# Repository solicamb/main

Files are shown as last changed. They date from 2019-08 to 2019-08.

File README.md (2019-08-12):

<p align="center">

</p>

SoliCamb is a student-led initiative from the University of Cambridge. In partnership with the Centre for Global Equality, we aim to develop a low cost, durable and easy to use sensing platform to measure soil carbon and moisture content. Soil health monitoring is essential for the wellbeing of the local ecosystem and, on a larger scale, indicative of global warming status. Through engaging citizen scientists in Cambridgeshire (UK) and overseas in Umzimvubu (South Africa), as well as providing access to analysed soil data, this initiative aims to empower and engage the public with global issues relating to environmental sustainability.

For more info, check out our:
* [Website](https://solicamb.co.uk)
* [Facebook](https://facebook.com/solicamb)
* [Twitter](https://twitter.com/solicamb)
* [Instagram](https://instagram.com/solicamb)

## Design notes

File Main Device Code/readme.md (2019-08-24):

The libraries required to run the code are: TinyGPS++, SPI.h, MFRC522.h, Adafruit_GFX.h, Adafruit_PCD8544.h, 
SdFat.h and SPI_anything.h 

Please follow the instructions here to ensure the libraries end up in the right place on you machine:
https://www.arduino.cc/en/guide/libraries

Follow these instructions to program the microcontroller: 
https://circuitdigest.com/microcontroller-projects/programming-stm32f103c8-board-using-usb-port

Authored by Sagnik Middya and James Meech

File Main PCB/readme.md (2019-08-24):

Link to BOM: https://octopart.com/bom-tool/TTlpAv4m

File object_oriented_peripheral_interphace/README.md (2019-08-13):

<p align="center">

</p>

# OBJECT ORIENTED PERIPHERAL INTERFACE (OOPI) 

OOPI is an SPI interface designed to facilitate communication between a master module and a sensor slave module. The interface aims to encapsulate and abstract the communications infrastructure so as to yield human-readable code which is naturally robust to erroneous implementation. Furthermore, OOPI is designed to function without the master module requiring knowledge of the nature of the attached sensor, which allows for the continuing, community-driven development of SoliCamb-compatibile sensors without neccessitating major firmware patches to the master module. Further information on the API can be found in the [summary](SUMMARY.md)

SoliCamb is a student-led initiative from the University of Cambridge. In partnership with the Centre for Global Equality, we aim to develop a low cost, durable and easy to use sensing platform to measure soil carbon and moisture content. Soil health monitoring is essential for the wellbeing of the local ecosystem and, on a larger scale, indicative of global warming status. Through engaging citizen scientists in Cambridgeshire (UK) and overseas in Umzimvubu (South Africa), as well as providing access to analysed soil data, this initiative aims to empower and engage the public with global issues relating to environmental sustainability.

For more info, check out our:
* [Website](https://solicamb.co.uk)
* [Facebook](https://facebook.com/solicamb)
* [Twitter](https://twitter.com/solicamb)
* [Instagram](https://instagram.com/solicamb)

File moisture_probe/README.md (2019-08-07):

This directory contains the code for the moisture retention probe.

# Development (debugging) version
There is a backend, which is [the Arduino code](./development/arduino_devel) for the microcontroller handling the measurements and transmitting them; and a frontend consisting of Python code plotting the data. It's purpose is to show the full data acquired during testing, and to save this data for further analysis.

For the latest moisture probe revisions based on BluePills, you can use the production version with a compile time flag set. See the `README` within [the BluePill development folder](./development/bluepill_devel).

# Production version
This consists of BluePill (STM32, Arduino-compatible, C) code that transmits a set of calculated, meaningful measures of soil health. Namely, a moisture level (wetness) and moisture retention (soil quality in resisting erosion) score is transmitted to the main device.

# Authorship
Initial version, 2019-07-16, jh2109

# Installation and dependencies
The Arduino code can be uploaded to any compatible board, testing has been performed on an Ardunio Uno and Micro. The BluePill code is compatible with the Arduino IDE once the STM32 has been installed via the board manager (see e.g. https://github.com/stm32duino/wiki/wiki/Getting-Started).

The supporting Python script used from a PC or Rasberry Pi is used to generate a csv file and display live sensor feedback. To run the python script some libraries should first be installed:

## Mac users
Python 3.x <br />
pip install pyqt5, pyqtgraph, pyserial

## Windows users
Python 3.x <br />
If using Anaconda or similar install pyserial, pyqtgraph and pyqt5

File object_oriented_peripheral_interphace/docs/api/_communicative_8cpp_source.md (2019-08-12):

# File Communicative.cpp

[**File List**](files.md) **>** [**Communicative.cpp**](_communicative_8cpp.md)

[Go to the documentation of this file.](_communicative_8cpp.md) 

````cpp

#include <Arduino.h>
#include "Communicative.h"
#include "SPI_InstructionSet.h"
#include <SPI.h>

const int REQUEST_DELAY_MICROS = 100;

// Constructor /////////////////////////////////////////////////////////////////
// Function that handles the creation and setup of instances

Communicative::Communicative(const int CS)
{

  ChipSelect = CS;
  SPISetup();

}

void Communicative::SPISetup(){

  // digitalWrite(ChipSelect, HIGH);  // ensure SS stays high for now

  // // Put SCK, MOSI, SS pins into output mode
  // // also put SCK, MOSI into LOW state, and SS into HIGH state.
  // // Then put SPI hardware into Master mode and turn SPI on
  // SPI.begin ();

  // // Slow down the master a bit
  // SPI.setClockDivider(SPI_CLOCK_DIV8);

  SPI.begin(); //Initialize the SPI_1 port.
  SPI.setBitOrder(MSBFIRST); // Set the SPI_1 bit order
  SPI.setDataMode(SPI_MODE0); //Set the  SPI_2 data mode 0
  SPI.setClockDivider(SPI_CLOCK_DIV16);      // Slow speed (72 / 16 = 4.5 MHz SPI_1 speed)
  pinMode(ChipSelect, OUTPUT);
}

Communicative::~Communicative(void){
  SPI.end();
}

// Public Methods //////////////////////////////////////////////////////////////
// Functions available in Wiring sketches, this library, and other libraries

bool Communicative::isPeripheralConnected(void){

  if (areYouAlive() == 0x06){
    return true;
  }else{
    return false;
  }

}

sCmd Communicative::RequestReply(const mCmd Request){

  digitalWrite(ChipSelect, LOW);  // enable Slave Select 

  sCmd Reply;
  
  //Initial Handshake  
   transferAndPause ('?');  // add command
   byte a = transferAndPause (0x00);

  if (a == 0x06){

    //Send Request
      SPI_write(Request);
      delay(REQUEST_DELAY_MICROS);

    //Recieve Reply
      SPI_read(Reply);

  }else{
    //Throw error due to failed handshake
  }

  // disable Slave Select
    digitalWrite(ChipSelect, HIGH);

  return Reply;

}

Identity Communicative::RequestIdentity(const mCmd Request){
  
  digitalWrite(ChipSelect, LOW);  // enable Slave Select 
  Identity Reply;
  
  //Initial Handshake  
   transferAndPause ('?');  // add command
   byte a = transferAndPause (0x00);

  if (a == 0x06){

    //Send Request
      SPI_write(Request);
      delay(REQUEST_DELAY_MICROS);

    //Recieve Reply
      SPI_read(Reply);

  }else{
    //Throw error due to failed handshake
  }

  // disable Slave Select
    digitalWrite(ChipSelect, HIGH);

  return Reply;

}

Data Communicative::RequestData(const mCmd Request){

  digitalWrite(ChipSelect, LOW);  // enable Slave Select 
  Data Reply;
  
  //Initial Handshake  
   transferAndPause ('?');  // add command
   byte a = transferAndPause (0x00);

  if (a == 0x06){

    //Send Request
      SPI_write(Request);
      delay(REQUEST_DELAY_MICROS);

    //Recieve Reply
      SPI_read(Reply);

  }else{
    //Throw error due to failed handshake
  }

  // disable Slave Select
    digitalWrite(ChipSelect, HIGH);

  return Reply;

}

// Private Methods /////////////////////////////////////////////////////////////
// Functions only available to other functions in this library

byte Communicative::transferAndPause(const byte what){

//  delay(100);
  byte a = SPI.transfer (what);
 delayMicroseconds (100);
    
  return a;
}

template <typename T> unsigned int Communicative::SPI_write (const T& value){
  
  const byte * p = (const byte*) &value;
  unsigned int i;
  for (i = 0; i < sizeof value; i++)
        transferAndPause(*p++);
  return i;
} 
    
template <typename T> unsigned int Communicative::SPI_read(T& value){

  byte * p = (byte*) &value;
  unsigned int i;
  for (i = 0; i < sizeof value; i++)
        *p++ = transferAndPause (0);
  return i;

}

byte Communicative::areYouAlive(){

   mCmd Request = {(mInstruct)IsThereData, (int)0,(float)0.0 };
   sCmd Reply;

  digitalWrite(ChipSelect, LOW);  // enable Slave Select 
  //digitalWrite(SS, LOW);
  
  //Initial Handshake  
   transferAndPause ('?');  // add command
   byte a = transferAndPause (0x00);

//    Serial.print("Recieved: ");
//    Serial.println(a);

  if (a == 0x06){

    //Send Request
      SPI_write(Request);
      delay(REQUEST_DELAY_MICROS);

    //Recieve Reply
      SPI_read(Reply);

  }else{
    //Throw error due to failed handshake
  }

  // disable Slave Select
    digitalWrite(ChipSelect, HIGH);
    //digitalWrite(SS, HIGH);

  return a;

} 
````

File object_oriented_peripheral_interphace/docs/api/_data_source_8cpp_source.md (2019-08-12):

# File DataSource.cpp

[**File List**](files.md) **>** [**DataSource.cpp**](_data_source_8cpp.md)

[Go to the documentation of this file.](_data_source_8cpp.md) 

````cpp
#include <Arduino.h>
#include "Instructable.h"
#include "DataSource.h"
#include "SPI_InstructionSet.h"

// Constructor /////////////////////////////////////////////////////////////////
// Function that handles the creation and setup of instances

DataSource::DataSource(const int ChipSelect): CommsModule(ChipSelect){

    //CurrentData.NumColumns = 0;
    CurrentData.NumRows = 0;

    for (int i = 0; i<NUMBER_OF_DATA_ROWS; i++){
        CurrentData.RowHeadings[i][0] = '\n';
        CurrentData.rowUnits[i][0] = '\n';
        CurrentData.NumColumns[i] = 0;

        for (int j = 0 ; j<DATA_ROW_LENGTH; j++){
            CurrentData.DataPoints[i][j] = 0.0;
        }
    }

}

// Public Methods //////////////////////////////////////////////////////////////
// Functions available in Wiring sketches, this library, and other libraries

bool DataSource::isThereData(void){
    mCmd Request = {(mInstruct)IsThereData,0,0.0};
    sCmd Reply = CommsModule.RequestReply(Request);

    if (Reply.Instruction == Yes){
        return true;
    }else{
        return false;
    }
}

Data DataSource::loadData(void){
    mCmd Request = {(mInstruct)SendDataPlease,0,0.0};
    CurrentData = CommsModule.RequestData(Request);
    return CurrentData;
}

int DataSource::getNumberOfDataColumns(const MeasurementVectors VectorNumber){
    return CurrentData.NumColumns[VectorNumber];
}

int DataSource::getNumberOfDataRows(void){
    return CurrentData.NumRows;
}

void DataSource::getRowHeadings(char Headings[NUMBER_OF_DATA_ROWS][ROW_HEADING_LENGTH]){

    for (int i = 0; i<NUMBER_OF_DATA_ROWS; i++){
        
        for(int j=0; j< ROW_HEADING_LENGTH; j++){

            Headings[i][j] = CurrentData.RowHeadings[i][j];

            if ('\n' ==  CurrentData.RowHeadings[i][j]) break;

        }
    }
}

void DataSource::getRowUnits(char Units[NUMBER_OF_DATA_ROWS][ROW_UNIT_LENGTH]){

    for (int i = 0; i<NUMBER_OF_DATA_ROWS; i++){
        
        for(int j=0; j< ROW_UNIT_LENGTH; j++){

            Units[i][j] = CurrentData.rowUnits[i][j];

            if ('\n' == CurrentData.rowUnits[i][j]) break;

        }
    }
}

void DataSource::getDataArray(float DataVals[NUMBER_OF_DATA_ROWS][DATA_ROW_LENGTH]){

    for (int i = 0; i<NUMBER_OF_DATA_ROWS; i++){
        
        for(int j=0; j< DATA_ROW_LENGTH; j++){

            DataVals[i][j] = CurrentData.DataPoints[i][j];

        }
    }

}

void DataSource::getDataVector(const MeasurementVectors VectorNumber, float DataVect[DATA_ROW_LENGTH]){

    switch (VectorNumber){

        case First:
            for (int i = 0; i < CurrentData.NumColumns[First]; i++){
                DataVect[i] = CurrentData.DataPoints[First][i];
            }
            break;

        case Second:
            for (int i = 0; i < CurrentData.NumColumns[Second]; i++){
                DataVect[i] = CurrentData.DataPoints[Second][i];
            }
            break;

        case Third:
            for (int i = 0; i < CurrentData.NumColumns[Third]; i++){
                DataVect[i] = CurrentData.DataPoints[Third][i];
            }
            break;
    }

}

int DataSource::getVectorLength(const MeasurementVectors VectorNumber){
    return CurrentData.NumColumns[VectorNumber];
}

 void DataSource::getVectorHeading(const MeasurementVectors VectorNumber, char Heading[ROW_HEADING_LENGTH]){

    switch (VectorNumber){

        case First:
            for (int i = 0; i < ROW_HEADING_LENGTH; i++){
                Heading[i] = CurrentData.RowHeadings[First][i];
                if ('\n' == CurrentData.RowHeadings[First][i]) break;
            }
            break;

        case Second:
            for (int i = 0; i < ROW_HEADING_LENGTH; i++){
                Heading[i] = CurrentData.RowHeadings[Second][i];
                if ('\n' == CurrentData.RowHeadings[Second][i]) break;
            }
            break;

        case Third:
            for (int i = 0; i < ROW_HEADING_LENGTH; i++){
                Heading[i] = CurrentData.RowHeadings[Third][i];
                if ('\n' == CurrentData.RowHeadings[Third][i]) break;
            }
            break;
    }

 }

 void DataSource::getVectorUnits(const MeasurementVectors VectorNumber, char Units[ROW_UNIT_LENGTH]){

    switch (VectorNumber){

        case First:
            for (int i = 0; i < ROW_UNIT_LENGTH; i++){
                Units[i] = CurrentData.rowUnits[First][i];
                if ('\n' == CurrentData.rowUnits[First][i]) break;
            }
            break;

        case Second:
            for (int i = 0; i < ROW_UNIT_LENGTH; i++){
                Units[i] = CurrentData.rowUnits[Second][i];
                if ('\n' == CurrentData.rowUnits[Second][i]) break;
            }
            break;

        case Third:
            for (int i = 0; i < ROW_UNIT_LENGTH; i++){
                Units[i] = CurrentData.rowUnits[Third][i];
                if ('\n' == CurrentData.rowUnits[Third][i]) break;
            }
            break;
    }

 }

float DataSource::getValueOne(void){
    return CurrentData.DataPoints[0][0];
}

float DataSource::getValueTwo(void){
    return CurrentData.DataPoints[1][0];
}

float DataSource::getValueThree(void){
    return CurrentData.DataPoints[2][0];
}

// Private Methods /////////////////////////////////////////////////////////////
// Functions only available to other functions in this library
````

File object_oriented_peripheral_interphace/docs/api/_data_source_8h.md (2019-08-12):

# File DataSource.h

[**File List**](files.md) **>** [**DataSource.h**](_data_source_8h.md)

[Go to the source code of this file.](_data_source_8h_source.md)

* `#include <Arduino.h>`
* `#include "SPI_InstructionSet.h"`
* `#include "Instructable.h"`

## Classes

| Type | Name |
| ---: | :--- |
| class | [**DataSource**](class_data_source.md) <br>_A class which models a Sensor/peripheral as an entity which is a source of data._  |

------------------------------
The documentation for this class was generated from the following file `DataSource.h`

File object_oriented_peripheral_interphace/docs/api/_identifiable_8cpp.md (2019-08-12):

# File Identifiable.cpp

[**File List**](files.md) **>** [**Identifiable.cpp**](_identifiable_8cpp.md)

[Go to the source code of this file.](_identifiable_8cpp_source.md)

* `#include <Arduino.h>`
* `#include "Identifiable.h"`
* `#include "SPI_InstructionSet.h"`
* `#include <SPI.h>`

------------------------------
The documentation for this class was generated from the following file `Identifiable.cpp`

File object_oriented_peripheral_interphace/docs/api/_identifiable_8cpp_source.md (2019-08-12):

# File Identifiable.cpp

[**File List**](files.md) **>** [**Identifiable.cpp**](_identifiable_8cpp.md)

[Go to the documentation of this file.](_identifiable_8cpp.md) 

````cpp

#include <Arduino.h>
#include "Identifiable.h"
#include "SPI_InstructionSet.h"
#include <SPI.h>

// Constructor /////////////////////////////////////////////////////////////////
// Function that handles the creation and setup of instances

Identifiable::Identifiable(const int ChipSelect): CommsModule(ChipSelect)
{

  if (CommsModule.isPeripheralConnected()){
    updateIdentity();
  }

  ThisSensor.sensorChipSelect = ChipSelect;

}

// Public Methods //////////////////////////////////////////////////////////////
// Functions available in Wiring sketches, this library, and other libraries

bool Identifiable::hasIdentityChanged(void){

  Identity connectedID;
  mCmd Request = {(mInstruct)WhoAreYou, (int)0,(float)0.0};

  connectedID = CommsModule.RequestIdentity(Request);

  if (connectedID.sensorID == ThisSensor.sensorID){
    return false;
  }else{
    return true;
  }

}

void Identifiable::updateIdentity(void){

  Identity connectedID;
  mCmd Request = {(mInstruct)WhoAreYou, (int)0,(float)0.0};

  connectedID = CommsModule.RequestIdentity(Request);

  ThisSensor.sensorID = connectedID.sensorID;

  for (int i =0; i<IDENTITY_SENSOR_NAME_LENGTH; i++){
    ThisSensor.SensorName[i] = connectedID.SensorName[i];
    if ('\n' == connectedID.SensorName[i]) break;
  }

}

int Identifiable::getIDNumber(void){
  return ThisSensor.sensorID;
}

void Identifiable::getSensorName(char name[IDENTITY_SENSOR_NAME_LENGTH]){

  for (int i = 0; i<IDENTITY_SENSOR_NAME_LENGTH; i++){
    name[i] = ThisSensor.SensorName[i];
    if ('\n' == ThisSensor.SensorName[i]) break;
  }

}
````

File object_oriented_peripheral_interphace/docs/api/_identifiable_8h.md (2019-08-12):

# File Identifiable.h

[**File List**](files.md) **>** [**Identifiable.h**](_identifiable_8h.md)

[Go to the source code of this file.](_identifiable_8h_source.md)

* `#include <Arduino.h>`
* `#include "SPI_InstructionSet.h"`
* `#include "Communicative.h"`

## Classes

| Type | Name |
| ---: | :--- |
| class | [**Identifiable**](class_identifiable.md) <br>_A class which models a Sensor/peripheral as an identifiable entity._  |

------------------------------
The documentation for this class was generated from the following file `Identifiable.h`

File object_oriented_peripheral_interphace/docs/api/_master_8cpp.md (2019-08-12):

# File Master.cpp

[**File List**](files.md) **>** [**Master.cpp**](_master_8cpp.md)

[Go to the source code of this file.](_master_8cpp_source.md)

* `#include <Arduino.h>`
* `#include "Master.h"`
* `#include "SPI_InstructionSet.h"`
* `#include <SPI.h>`
* `#include "SPI_Anything_Slave.h"`

## Public Attributes

| Type | Name |
| ---: | :--- |
|  [**Master**](class_master.md) | [**SensorMaster**](_master_8cpp.md#variable-sensormaster)  <br>_Auto-instantiated instance of_ [_**Master**_](class_master.md) _class, called during the privately implemented IRQ routine and accessible externally by main code._ |

## Public Functions

| Type | Name |
| ---: | :--- |
|  void | [**SPI\_IRQ**](_master_8cpp.md#function-spi-irq) (void) <br>_Innaccesible IRQ, called on SS falling._  |

## Public Attributes Documentation

### <a href="#variable-sensormaster" id="variable-sensormaster">variable SensorMaster </a>

```cpp
volatile Master SensorMaster;
```

## Public Functions Documentation

### <a href="#function-spi-irq" id="function-spi-irq">function SPI\_IRQ </a>

```cpp
void SPI_IRQ (
    void
) 
```

------------------------------
The documentation for this class was generated from the following file `Master.cpp`

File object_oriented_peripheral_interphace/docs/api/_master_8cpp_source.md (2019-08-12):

# File Master.cpp

[**File List**](files.md) **>** [**Master.cpp**](_master_8cpp.md)

[Go to the documentation of this file.](_master_8cpp.md) 

````cpp

#include <Arduino.h>
#include "Master.h"
#include "SPI_InstructionSet.h"
#include <SPI.h>
#include "SPI_Anything_Slave.h"

// Constructor /////////////////////////////////////////////////////////////////
// Function that handles the creation and setup of instances

  Master::Master(){
  //   CurrentRequest = (mCmd){SitRep,0,0.0};

  //   //Initialise Identity
  //   ThisSensorID.sensorID = 0;
  //   ThisSensorID.sensorChipSelect = 0;

  //   for (int i =0; i< IDENTITY_SENSOR_NAME_LENGTH; i++){
  //     ThisSensorID.SensorName[i] = '\n';
  //   }

  // //Initialise User Instruction Set
  //   UserInstructionSet.NumOfInstructions = 0;
  //   UserInstructionSet.InstructionCounter = 0;

  //   for (int i = 0; i<MAX_USER_INSTRUCTION_NUMBER; i++){

  //     UserInstructionSet.MasterInstructionSet[i] = NAK;
  //     UserInstructionSet.iParams[i] = 0;
  //     UserInstructionSet.fParams[i] = 0.0;

  //     for (int j = 0; j<SLAVE_COMMMAND_STRING_LENGTH;j++){
  //       UserInstructionSet.InstructionSet[i][j] = '\n';
  //     }
  //   }

  // //Initialise Data
  //   //MeasurementData.NumColumns = 0;
  //   MeasurementData.NumRows = 0;

  //   for (int i = 0; i<NUMBER_OF_DATA_ROWS; i++){
  //     MeasurementData.RowHeadings[i][0] = '\n';
  //     MeasurementData.rowUnits[i][0] = '\n';
  //     MeasurementData.NumColumns[i] = 0;

  //     for (int j = 0 ; j<DATA_ROW_LENGTH; j++){
  //       MeasurementData.DataPoints[i][j] = 0.0;
  //     }
  //   }

  //Setup Slave SPI
    //SPISetup();
  }

  Master::Master(const int SensorIDNumber, const char SensorName[], const char InstructionSet[][SLAVE_COMMMAND_STRING_LENGTH], const int NumberOfInstructions, const sInstruct MasterInstructionSet[], const int intParams[], const float floatParams[]){

    beginMeasurementYet = false;

  //Initialise Identity
    ThisSensorID.sensorID = SensorIDNumber;
    ThisSensorID.sensorChipSelect = 0;

    for (int i =0; i< IDENTITY_SENSOR_NAME_LENGTH; i++){
      ThisSensorID.SensorName[i] = SensorName[i];
      if ('\n' == SensorName[i]) break;
    }

  //Initialise User Instruction Set
    UserInstructionSet.NumOfInstructions = NumberOfInstructions;
    UserInstructionSet.InstructionCounter = 0;

    for (int i = 0; i<NumberOfInstructions; i++){

      UserInstructionSet.MasterInstructionSet[i] = MasterInstructionSet[i];
      UserInstructionSet.iParams[i] = intParams[i];
      UserInstructionSet.fParams[i] = floatParams[i];

      for (int j = 0; j<SLAVE_COMMMAND_STRING_LENGTH;j++){
        UserInstructionSet.InstructionSet[i][j] = InstructionSet[i][j];
        if (InstructionSet[i][j] == '\n') break;
      }
    }

  //Initialise Data
    //MeasurementData.NumColumns = 0;
    MeasurementData.NumRows = 0;

    for (int i = 0; i<NUMBER_OF_DATA_ROWS; i++){
      MeasurementData.RowHeadings[i][0] = '\n';
      MeasurementData.rowUnits[i][0] = '\n';
      MeasurementData.NumColumns[i] = 0;

      for (int j = 0 ; j<DATA_ROW_LENGTH; j++){
        MeasurementData.DataPoints[i][j] = 0.0;
      }
    }

  //Setup Slave SPI
    //SPISetup();

}

 void Master::SETUP(const int SensorIDNumber, volatile char SensorName[], volatile char InstructionSet[][SLAVE_COMMMAND_STRING_LENGTH], const int NumberOfInstructions, volatile sInstruct MasterInstructionSet[], volatile int intParams[], volatile float floatParams[]) volatile{
    
    beginMeasurementYet = false;  

    //Initialise Identity
    ThisSensorID.sensorID = SensorIDNumber;
    ThisSensorID.sensorChipSelect = 0;

    for (int i =0; i< IDENTITY_SENSOR_NAME_LENGTH; i++){
      ThisSensorID.SensorName[i] = SensorName[i];
      if ('\n' == SensorName[i]) break;
    }

  //Initialise User Instruction Set
    UserInstructionSet.NumOfInstructions = NumberOfInstructions;
    UserInstructionSet.InstructionCounter = 0;

    for (int i = 0; i<NumberOfInstructions; i++){

      UserInstructionSet.MasterInstructionSet[i] = MasterInstructionSet[i];
      UserInstructionSet.iParams[i] = intParams[i];
      UserInstructionSet.fParams[i] = floatParams[i];

      for (int j = 0; j<SLAVE_COMMMAND_STRING_LENGTH;j++){
        UserInstructionSet.InstructionSet[i][j] = InstructionSet[i][j];
        if (InstructionSet[i][j] == '\n') break;
      }
    }

  //Initialise Data
    //MeasurementData.NumColumns = 0;
    MeasurementData.NumRows = 0;

    for (int i = 0; i<NUMBER_OF_DATA_ROWS; i++){
      MeasurementData.RowHeadings[i][0] = '\n';
      MeasurementData.rowUnits[i][0] = '\n';
      MeasurementData.NumColumns[i] = 0;

      for (int j = 0 ; j<DATA_ROW_LENGTH; j++){
        MeasurementData.DataPoints[i][j] = 0.0;
      }
    }

  //Setup SPI and interrup

    SPISetup();
    
 }

void Master::SPISetup() volatile{

  //  // have to send on master in, *slave out*
  // pinMode(MISO, OUTPUT);

  // // turn on SPI in slave mode
  // SPCR |= _BV(SPE);

  // // turn on interrupts
  // SPCR |= _BV(SPIE);

   SPI.beginTransactionSlave(SPISettings(18000000, MSBFIRST, SPI_MODE0, DATA_SIZE_8BIT));
   attachInterrupt(SPI1_NSS_PIN , SPI_IRQ, FALLING);

}

Master::~Master(void){
  //SPI.end();
}

Master::Master(volatile const Master& rhs){
  Serial.println("Copy");
  Serial.println(millis());
  this->CurrentRequest = rhs.CurrentRequest;
  this->ThisSensorID = rhs.ThisSensorID;
  this->MeasurementData = rhs.MeasurementData;
  this->UserInstructionSet = rhs.UserInstructionSet;;
}

// Public Methods //////////////////////////////////////////////////////////////
// Functions available in Wiring sketches, this library, and other libraries
  //Communications Interface
      bool Master::Handshake(void) volatile{
        // byte Ping = SPDR;
        uint8_t Ping = SPI.read();
        if (Ping == '?'){
          SPI.transfer(0x06);
          return true;
        }else{
          return false;
        }
      }

      mCmd Master::loadRequest(void) volatile{
        SPI_read(CurrentRequest);
        return CurrentRequest;
      }

      mInstruct Master::getCurrentInstruction(void) volatile{
        return CurrentRequest.Instruction;
      }

      int Master::getCurrentInstructionIntParameter(void) volatile{
        return CurrentRequest.iParam;
      }

      float Master::getCurrentInstructionFloatParameter(void) volatile{
        return CurrentRequest.fParam;
      }

      void Master::sendReply(const sCmd Reply) volatile{
        // SPI_write(Reply);
        SPI_writeAnything(Reply);
      }

      void Master::sendReply(const sInstruct Instruction) volatile{
        sCmd Reply = {Instruction,"",0,0.0};
      
        SPI_write(Reply);
      }

      void Master::sendReply(const sInstruct Instruction, volatile char InstructionString[SLAVE_COMMMAND_STRING_LENGTH]) volatile{
        sCmd Reply = {Instruction,"",0,0.0};

        for (int i = 0; i<SLAVE_COMMMAND_STRING_LENGTH; i++){
          Reply.sParam[i] = InstructionString[i];
          if (InstructionString[i] == '\n') break;
        }
      
        SPI_write(Reply);

      }

      void Master::sendReply(const sInstruct Instruction, const int iParam) volatile{
      
        SPI_write((sCmd){Instruction,"",iParam,0.0});
      
      }

      void Master::sendReply(const sInstruct Instruction, const float fParam) volatile{

        SPI_write((sCmd){Instruction,"",0,fParam});

      }

      void Master::sendReply(const sInstruct Instruction, const int iParam, const int fParam) volatile{

        SPI_write((sCmd){Instruction,"",iParam,fParam});

      }

      void Master::sendReply( sInstruct Instruction,  int iParam, volatile char InstructionString[SLAVE_COMMMAND_STRING_LENGTH]) volatile{

        sCmd Reply = {Instruction,"",iParam,0.0};

        for (int i = 0; i<SLAVE_COMMMAND_STRING_LENGTH; i++){
          Reply.sParam[i] = InstructionString[i];
          if (InstructionString[i] == '\n') break;
        }

        SPI_write(Reply);

      }
      
      void Master::sendReply( sInstruct Instruction,  float fParam, volatile char InstructionString[SLAVE_COMMMAND_STRING_LENGTH]) volatile{

        sCmd Reply = {Instruction,"",0,fParam};

        for (int i = 0; i<SLAVE_COMMMAND_STRING_LENGTH; i++){
          Reply.sParam[i] = InstructionString[i];
          if (InstructionString[i] == '\n') break;
        }

        SPI_write(Reply);

      }

      void Master::sendReply( sInstruct Instruction, int iParam, float fParam, volatile char InstructionString[SLAVE_COMMMAND_STRING_LENGTH]) volatile{

      sCmd Reply = {Instruction,"",iParam,fParam};

        for (int i = 0; i<SLAVE_COMMMAND_STRING_LENGTH; i++){
          Reply.sParam[i] = InstructionString[i];
          if (InstructionString[i] == '\n') break;
        }

        SPI_write(Reply);

      }

      void Master::sendData(void) volatile{
          SPI_write(MeasurementData);
      }

      void Master::sendIdentity(void) volatile{
        SPI_write(ThisSensorID);
      }

    //Data handling interface
      bool Master::PushMeasurementVector(const MeasurementVectors VectorNumber, const float Measurement) volatile{

        switch (VectorNumber){

          case First:
            if (MeasurementData.NumColumns[First] == DATA_ROW_LENGTH) return false;
            MeasurementData.DataPoints[First][MeasurementData.NumColumns[First]] = Measurement;
            MeasurementData.NumColumns[First]++;
            break;

          case Second:
            if (MeasurementData.NumColumns[Second] == DATA_ROW_LENGTH) return false;
            MeasurementData.DataPoints[Second][MeasurementData.NumColumns[Second]] = Measurement;
            MeasurementData.NumColumns[Second]++;
            break;

          case Third:
            if (MeasurementData.NumColumns[Third] == DATA_ROW_LENGTH) return false;
            MeasurementData.DataPoints[Third][MeasurementData.NumColumns[Third]] = Measurement;
            MeasurementData.NumColumns[Third]++;
            break;

        }

        return true;

      }

      bool Master::PopMeasurementVector( MeasurementVectors VectorNumber)volatile{

        switch (VectorNumber){

          case First:
            if (MeasurementData.NumColumns[First] == 0) return false;
            MeasurementData.NumColumns[First]--;
            break;

          case Second:
            if (MeasurementData.NumColumns[Second] == 0) return false;
            MeasurementData.NumColumns[Second]--;
            break;

          case Third:
            if (MeasurementData.NumColumns[Third] == 0) return false;
            MeasurementData.NumColumns[Third]--;
            break;

        }

        return true;

      }

      void Master::ClearMeasurementVector( MeasurementVectors VectorNumber)volatile{

        switch (VectorNumber){

          case First:
            MeasurementData.NumColumns[First] = 0;
            break;

          case Second:
            MeasurementData.NumColumns[Second] = 0;
            break;

          case Third:
            MeasurementData.NumColumns[Third] = 0;
            break;

        }

      }

      void Master::setMeasurementVectorHeading( MeasurementVectors VectorNumber, volatile char Heading[ROW_HEADING_LENGTH])volatile{

        switch (VectorNumber){

          case First:
            for (int i =0; i<ROW_HEADING_LENGTH; i++){
              MeasurementData.RowHeadings[First][i] = Heading[i];
              if (Heading[i] == '\n') break;
            }
            break;

          case Second:
            for (int i =0; i<ROW_HEADING_LENGTH; i++){
              MeasurementData.RowHeadings[Second][i] = Heading[i];
              if (Heading[i] == '\n') break;
            }
            break;

          case Third:
            for (int i =0; i<ROW_HEADING_LENGTH; i++){
              MeasurementData.RowHeadings[Third][i] = Heading[i];
              if (Heading[i] == '\n') break;
            }
            break;

        }

      }

      void Master::setMeasurementVectorUnits(MeasurementVectors VectorNumber, volatile char Units[ROW_UNIT_LENGTH])volatile{

        switch (VectorNumber){

          case First:
            for (int i =0; i<ROW_UNIT_LENGTH; i++){
              MeasurementData.rowUnits[First][i] = Units[i];
              if (Units[i] == '\n') break;
            }
            break;

          case Second:
            for (int i =0; i<ROW_UNIT_LENGTH; i++){
              MeasurementData.rowUnits[Second][i] = Units[i];
              if (Units[i] == '\n') break;
            }
            break;

          case Third:
            for (int i =0; i<ROW_UNIT_LENGTH; i++){
              MeasurementData.rowUnits[Third][i] = Units[i];
              if (Units[i] == '\n') break;
            }
            break;

      }

    }

      bool Master::isThereData(void) volatile{

        if ((MeasurementData.NumColumns[First] > 0) || (MeasurementData.NumColumns[Second] > 0) ||(MeasurementData.NumColumns[Third] > 0)){
          return true;
        } else{
          return false;
        }
      }

    //User Instruction Interface
      void Master::sendTotalNumOfInstructions(void) volatile{
        sendReply((sInstruct)ReferToInt,UserInstructionSet.NumOfInstructions);
      }

      int Master::getCurrentInstructionNumber(void) volatile{
        return UserInstructionSet.InstructionCounter;
      }

      bool Master::sendNextUserInstruction(void) volatile{

        if (UserInstructionSet.InstructionCounter == UserInstructionSet.NumOfInstructions){
          return false;
        }

        int Counter = UserInstructionSet.InstructionCounter;
        sendReply(UserInstructionSet.MasterInstructionSet[Counter], UserInstructionSet.iParams[Counter], UserInstructionSet.fParams[Counter], UserInstructionSet.InstructionSet[Counter]);
      
        UserInstructionSet.InstructionCounter++;

        return true;
      }

      void Master::resendCurrentUserInstruction(void) volatile{
        int Counter = UserInstructionSet.InstructionCounter;
        sendReply(UserInstructionSet.MasterInstructionSet[Counter], UserInstructionSet.iParams[Counter], UserInstructionSet.fParams[Counter], UserInstructionSet.InstructionSet[Counter]);
       }

      void Master::restartUserInstructionCycle(void) volatile{
        UserInstructionSet.InstructionCounter = 0;
      }

      void Master::beginMeasurement(void) volatile{
        beginMeasurementYet = true;
        SensorMaster.sendReply(ACK);
      }

      bool Master::shallIStart(void) volatile{
        if (beginMeasurementYet){
          beginMeasurementYet = false; //reset
          return true;
        } else{
          return beginMeasurementYet;
        }

      }

// Private Methods /////////////////////////////////////////////////////////////
// Functions only available to other functions in this library

template <typename T> unsigned int Master::SPI_write (const T& value) volatile{
  const byte * p = (const byte*) &value;
    unsigned int i;
    for (i = 0; i < sizeof value; i++)
          SPI.transfer(*p++);
    return i;
}

template <typename T> unsigned int Master::SPI_read(T& value) volatile{
  byte * p = (byte*) &value;
    unsigned int i;
    for (i = 0; i < sizeof value; i++)
          *p++ = SPI.transfer (0);
    return i;
}

volatile Master SensorMaster;

void SPI_IRQ(void){
  
      if (SensorMaster.Handshake()){
        
      //Retrieve the request from Master
          mCmd Request = SensorMaster.loadRequest();

      //Call Request Handler
          RequestHandler(Request);
    }//End of transaction

}
````

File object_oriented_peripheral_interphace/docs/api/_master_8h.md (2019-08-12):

# File Master.h

[**File List**](files.md) **>** [**Master.h**](_master_8h.md)

[Go to the source code of this file.](_master_8h_source.md)

* `#include <Arduino.h>`
* `#include "SPI_InstructionSet.h"`

## Classes

| Type | Name |
| ---: | :--- |
| class | [**Master**](class_master.md) <br>_A monolithic class to encapsulate and abstract the slave's communication with the master._  |
| struct | [**UserInstructions**](struct_user_instructions.md) <br> |

## Public Attributes

| Type | Name |
| ---: | :--- |
|  const int | [**MAX\_USER\_INSTRUCTION\_NUMBER**](_master_8h.md#variable-max-user-instruction-number) = = 5<br> |
|  [**Master**](class_master.md) | [**SensorMaster**](_master_8h.md#variable-sensormaster)  <br>_Auto-instantiated instance of_ [_**Master**_](class_master.md) _class, called during the privately implemented IRQ routine and accessible externally by main code._ |

## Public Functions

| Type | Name |
| ---: | :--- |
|  void | [**RequestHandler**](_master_8h.md#function-requesthandler) ([**mCmd**](structm_cmd.md) & Request) <br>_Function prototype for user-implemented IRQ method; called after handshake and the reconstruction of the request from the master._  |
|  void | [**SPI\_IRQ**](_master_8h.md#function-spi-irq) (void) <br>_Innaccesible IRQ, called on SS falling._  |

## Macros

| Type | Name |
| ---: | :--- |
| define  | [**SPI1\_NSS\_PIN**](_master_8h.md#define-spi1-nss-pin)  () PA4<br> |

## Public Attributes Documentation

### <a href="#variable-max-user-instruction-number" id="variable-max-user-instruction-number">variable MAX\_USER\_INSTRUCTION\_NUMBER </a>

```cpp
const int MAX_USER_INSTRUCTION_NUMBER;
```

### <a href="#variable-sensormaster" id="variable-sensormaster">variable SensorMaster </a>

```cpp
volatile Master SensorMaster;
```

## Public Functions Documentation

### <a href="#function-requesthandler" id="function-requesthandler">function RequestHandler </a>

```cpp
void RequestHandler (
    mCmd & Request
) 
```

### <a href="#function-spi-irq" id="function-spi-irq">function SPI\_IRQ </a>

```cpp
void SPI_IRQ (
    void
) 
```

## Macro Definition Documentation

### <a href="#define-spi1-nss-pin" id="define-spi1-nss-pin">define SPI1\_NSS\_PIN </a>

```cpp
#define SPI1_NSS_PIN () 
```

------------------------------
The documentation for this class was generated from the following file `Master.h`

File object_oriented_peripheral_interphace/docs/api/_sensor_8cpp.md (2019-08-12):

# File Sensor.cpp

[**File List**](files.md) **>** [**Sensor.cpp**](_sensor_8cpp.md)

[Go to the source code of this file.](_sensor_8cpp_source.md)

* `#include <Arduino.h>`
* `#include "DataSource.h"`
* `#include "Instructor.h"`
* `#include "Instructable.h"`
* `#include "Identifiable.h"`
* `#include "Sensor.h"`
* `#include "SPI_InstructionSet.h"`

------------------------------
The documentation for this class was generated from the following file `Sensor.cpp`

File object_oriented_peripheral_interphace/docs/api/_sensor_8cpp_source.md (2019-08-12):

# File Sensor.cpp

[**File List**](files.md) **>** [**Sensor.cpp**](_sensor_8cpp.md)

[Go to the documentation of this file.](_sensor_8cpp.md) 

````cpp
#include <Arduino.h>
#include "DataSource.h"
#include "Instructor.h"
#include "Instructable.h"
#include "Identifiable.h"
#include "Sensor.h"
#include "SPI_InstructionSet.h"

// Constructor /////////////////////////////////////////////////////////////////
// Function that handles the creation and setup of instances

Sensor::Sensor(const int ChipSelect): Instructable(ChipSelect), Instructor(ChipSelect), DataSource(ChipSelect), Identifiable(ChipSelect){

}

// Public Methods //////////////////////////////////////////////////////////////
// Functions available in Wiring sketches, this library, and other libraries

int Sensor::StartMeasurement(void){

    bool Ans = issueCommand(BeginMeasurement);

    return Ans;

}

int Sensor::PauseMeasurementForMillis(int PauseTime){

    return issueCommand(PauseMeasurementForiParam, PauseTime);

}

int Sensor::RestartMeasurement(void){

    return issueCommand(RestartMeasurementProcedure);

}

// Private Methods /////////////////////////////////////////////////////////////
// Functions only available to other functions in this library
````

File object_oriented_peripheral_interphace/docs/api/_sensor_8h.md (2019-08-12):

# File Sensor.h

[**File List**](files.md) **>** [**Sensor.h**](_sensor_8h.md)

[Go to the source code of this file.](_sensor_8h_source.md)

* `#include <Arduino.h>`
* `#include "SPI_InstructionSet.h"`
* `#include "Instructor.h"`
* `#include "DataSource.h"`
* `#include "Instructable.h"`
* `#include "Identifiable.h"`

## Classes

| Type | Name |
| ---: | :--- |
| class | [**Sensor**](class_sensor.md) <br>_A class which models a Sensor/peripheral._  |

------------------------------
The documentation for this class was generated from the following file `Sensor.h`

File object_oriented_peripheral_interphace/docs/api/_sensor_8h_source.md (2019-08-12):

# File Sensor.h

[**File List**](files.md) **>** [**Sensor.h**](_sensor_8h.md)

[Go to the documentation of this file.](_sensor_8h.md) 

````cpp

// ensure this library description is only included once
#ifndef Sensor_h
#define Sensor_h

// include types & constants of Wiring core API
#include <Arduino.h>
#include "SPI_InstructionSet.h"
#include "Instructor.h"
#include "DataSource.h"
#include "Instructable.h"
#include "Identifiable.h"

// library interface description

  // library interface description

 class Sensor: public Instructable, public Instructor, public DataSource, public Identifiable
{
  // user-accessible "public" interface
  public:

    Sensor(const int ChipSelect);

    int StartMeasurement(void);

    int PauseMeasurementForMillis(int);

    int RestartMeasurement(void);

  // library-accessible "private" interface
  private:

};

#endif
````

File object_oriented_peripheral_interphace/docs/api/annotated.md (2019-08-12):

# Class List

Here are the classes, structs, unions and interfaces with brief descriptions:

* **class** [**Communicative**](class_communicative.md) _A class to manage communication with slave module._   
* **struct** [**Data**](struct_data.md) _Type used to encapsulate the data collected by the slave._   
* **class** [**DataSource**](class_data_source.md) _A class which models a Sensor/peripheral as an entity which is a source of data._   
* **class** [**Identifiable**](class_identifiable.md) _A class which models a Sensor/peripheral as an identifiable entity._   
* **struct** [**Identity**](struct_identity.md) _Type used to convey the Slave identity._   
* **class** [**Instructable**](class_instructable.md) _A class which models a Sensor/peripheral as entity which can recieve commands._   
* **class** [**Instructor**](class_instructor.md) _A class which models a Sensor/peripheral as entity which can issue instructions to the master._   
* **class** [**Master**](class_master.md) _A monolithic class to encapsulate and abstract the slave's communication with the master._   
* **class** [**Sensor**](class_sensor.md) _A class which models a Sensor/peripheral._   
* **struct** [**UserInstructions**](struct_user_instructions.md)   
* **struct** [**mCmd**](structm_cmd.md) _Type used by master to send requests to slave._   
* **struct** [**sCmd**](structs_cmd.md) _Type used by slave to send reply to master,._

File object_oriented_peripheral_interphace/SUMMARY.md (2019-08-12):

# Table of contents

* [Object Oriented Peripheral Interface (OOPI)](README.md)
  * [Class List](docs/api/annotated.md)
    * [class Communicative](docs/api/class_communicative.md)
    * [struct Data](docs/api/struct_data.md)
    * [class DataSource](docs/api/class_data_source.md)
    * [class Identifiable](docs/api/class_identifiable.md)
    * [struct Identity](docs/api/struct_identity.md)
    * [class Instructable](docs/api/class_instructable.md)
    * [class Instructor](docs/api/class_instructor.md)
    * [class Master](docs/api/class_master.md)
    * [class Sensor](docs/api/class_sensor.md)
    * [struct UserInstructions](docs/api/struct_user_instructions.md)
    * [struct mCmd](docs/api/structm_cmd.md)
    * [struct sCmd](docs/api/structs_cmd.md)
  * [Class Index](docs/api/classes.md)
  * [Class Hierarchy](docs/api/hierarchy.md)
  * [Class Members](docs/api/class_members.md)
  * [Class Member Functions](docs/api/class_member_functions.md)
  * [Class Member Variables](docs/api/class_member_variables.md)
  * [Class Member Typedefs](docs/api/class_member_typedefs.md)
  * [Class Member Enumerations](docs/api/class_member_enums.md)
  * [Files](docs/api/files.md)
    * [Communicative.cpp](docs/api/_communicative_8cpp.md)
    * [Communicative.cpp source](docs/api/_communicative_8cpp_source.md)
    * [Communicative.h](docs/api/_communicative_8h.md)
    * [Communicative.h source](docs/api/_communicative_8h_source.md)
    * [DataSource.cpp](docs/api/_data_source_8cpp.md)
    * [DataSource.cpp source](docs/api/_data_source_8cpp_source.md)
    * [DataSource.h](docs/api/_data_source_8h.md)
    * [DataSource.h source](docs/api/_data_source_8h_source.md)
    * [Identifiable.cpp](docs/api/_identifiable_8cpp.md)
    * [Identifiable.cpp source](docs/api/_identifiable_8cpp_source.md)
    * [Identifiable.h](docs/api/_identifiable_8h.md)
    * [Identifiable.h source](docs/api/_identifiable_8h_source.md)
    * [Instructable.cpp](docs/api/_instructable_8cpp.md)
    * [Instructable.cpp source](docs/api/_instructable_8cpp_source.md)
    * [Instructable.h](docs/api/_instructable_8h.md)
    * [Instructable.h source](docs/api/_instructable_8h_source.md)
    * [Instructor.cpp](docs/api/_instructor_8cpp.md)
    * [Instructor.cpp source](docs/api/_instructor_8cpp_source.md)
    * [Instructor.h](docs/api/_instructor_8h.md)
    * [Instructor.h source](docs/api/_instructor_8h_source.md)
    * [Master.cpp](docs/api/_master_8cpp.md)
    * [Master.cpp source](docs/api/_master_8cpp_source.md)
    * [Master.h](docs/api/_master_8h.md)
    * [Master.h source](docs/api/_master_8h_source.md)
    * [SPI_InstructionSet.h](docs/api/_s_p_i___instruction_set_8h.md)
    * [SPI_InstructionSet.h source](docs/api/_s_p_i___instruction_set_8h_source.md)
    * [Sensor.cpp](docs/api/_sensor_8cpp.md)
    * [Sensor.cpp source](docs/api/_sensor_8cpp_source.md)
    * [Sensor.h](docs/api/_sensor_8h.md)
    * [Sensor.h source](docs/api/_sensor_8h_source.md)
  * [File Variables](docs/api/variables.md)
  * [File Functions](docs/api/functions.md)
  * [File Macros](docs/api/macros.md)

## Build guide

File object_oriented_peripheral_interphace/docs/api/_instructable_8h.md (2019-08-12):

# File Instructable.h

[**File List**](files.md) **>** [**Instructable.h**](_instructable_8h.md)

[Go to the source code of this file.](_instructable_8h_source.md)

* `#include <Arduino.h>`
* `#include "SPI_InstructionSet.h"`
* `#include "Communicative.h"`

## Classes

| Type | Name |
| ---: | :--- |
| class | [**Instructable**](class_instructable.md) <br>_A class which models a Sensor/peripheral as entity which can recieve commands._  |

------------------------------
The documentation for this class was generated from the following file `Instructable.h`

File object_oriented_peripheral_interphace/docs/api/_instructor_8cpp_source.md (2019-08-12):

# File Instructor.cpp

[**File List**](files.md) **>** [**Instructor.cpp**](_instructor_8cpp.md)

[Go to the documentation of this file.](_instructor_8cpp.md) 

````cpp
#include <Arduino.h>
#include "Instructable.h"
#include "Instructor.h"
#include "SPI_InstructionSet.h"

// Constructor /////////////////////////////////////////////////////////////////
// Function that handles the creation and setup of instances

Instructor::Instructor(const int ChipSelect): CommsModule(ChipSelect){
    CurrentCommand.Instruction = NAK;
    CurrentCommand.sParam[0] = '\n';
    CurrentCommand.iParam = 0;
    CurrentCommand.fParam = 0.0;
}

// Public Methods //////////////////////////////////////////////////////////////
// Functions available in Wiring sketches, this library, and other libraries

int Instructor::howManyInstructions(void){
    mCmd Request = {(mInstruct)HowManyInstructions,0,0.0};
    sCmd Reply = CommsModule.RequestReply(Request);
    return Reply.iParam;
}

int Instructor::howLongShouldIWait(void){
    mCmd Request = {(mInstruct)HowLongShouldIWait,0,0.0};
    sCmd Reply = CommsModule.RequestReply(Request);
    return Reply.iParam;
}

void Instructor::loadNextCommand(void){
     mCmd Request = {(mInstruct)NextCommandPlease,0,0.0};
    // sCmd Reply = CommsModule.RequestReply(Request);
    // CurrentCommand = Reply;
    //return CurrentCommand;
    //mCmd Request = {(mInstruct)IsThereData,0,0.0};
    sCmd Reply = CommsModule.RequestReply(Request);
    CurrentCommand = Reply;
}

void Instructor::getCurrentCommandString(char Instruction[SLAVE_COMMMAND_STRING_LENGTH]){
    for (int i = 0; i < SLAVE_COMMMAND_STRING_LENGTH; i++){
        Instruction[i] = CurrentCommand.sParam[i];
        if (CurrentCommand.sParam[i] == '\n') break;
    }
}

int Instructor::getCurrentCommandInt(void){
    return CurrentCommand.iParam;
}

float Instructor::getCurrentCommandFloat(void){
    return CurrentCommand.fParam;
}

sInstruct Instructor::getCurrentCommandInstruction(void){
    return CurrentCommand.Instruction;
}

// Private Methods /////////////////////////////////////////////////////////////
// Functions only available to other functions in this library
````

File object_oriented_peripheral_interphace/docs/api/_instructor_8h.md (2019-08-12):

# File Instructor.h

[**File List**](files.md) **>** [**Instructor.h**](_instructor_8h.md)

[Go to the source code of this file.](_instructor_8h_source.md)

* `#include <Arduino.h>`
* `#include "SPI_InstructionSet.h"`
* `#include "Instructable.h"`

## Classes

| Type | Name |
| ---: | :--- |
| class | [**Instructor**](class_instructor.md) <br>_A class which models a Sensor/peripheral as entity which can issue instructions to the master._  |

------------------------------
The documentation for this class was generated from the following file `Instructor.h`

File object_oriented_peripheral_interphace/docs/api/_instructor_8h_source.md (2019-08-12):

# File Instructor.h

[**File List**](files.md) **>** [**Instructor.h**](_instructor_8h.md)

[Go to the documentation of this file.](_instructor_8h.md) 

````cpp

// ensure this library description is only included once
#ifndef Instructor_h
#define Instructor_h

// include types & constants of Wiring core API
#include <Arduino.h>
#include "SPI_InstructionSet.h"
#include "Instructable.h"
// library interface description

class Instructor
{
  // user-accessible "public" interface
  public:

    Instructor(const int ChipSelect);

    int howManyInstructions(void);

    int howLongShouldIWait(void);

    void loadNextCommand(void);

    void getCurrentCommandString(char[SLAVE_COMMMAND_STRING_LENGTH]);

    int getCurrentCommandInt(void);

    float getCurrentCommandFloat(void);

    sInstruct getCurrentCommandInstruction(void);

  // library-accessible "private" interface
  private:
    sCmd CurrentCommand;
    Communicative CommsModule;
};

#endif
````

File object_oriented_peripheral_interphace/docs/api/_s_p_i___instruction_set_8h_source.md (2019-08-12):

# File SPI\_InstructionSet.h

[**File List**](files.md) **>** [**SPI\_InstructionSet.h**](_s_p_i___instruction_set_8h.md)

[Go to the documentation of this file.](_s_p_i___instruction_set_8h.md) 

````cpp
#ifndef SPIINSTRUCTIONSET_H
#define SPIINSTRUCTIONSET_H

typedef enum sInstruct{
  DisplayInstructionAndWait, 
  DisplayInstructionAndWaitForUser, 
  DontDisplayAndWait, 
  DontDisplayAndContinue, 
  ACK, 
  Yes, 
  No, 
  NAK, 
  ReferToInt, 
  ReferToFloat, 
  ReferToString 
}; 

typedef enum mInstruct{
  PauseMeasurementForiParam, 
  RestartMeasurementProcedure, 
  ResetDevice, 
  HowManyInstructions, 
  NextCommandPlease, 
  IsThereData, 
  SendDataPlease, 
  WhoAreYou, 
  HowLongShouldIWait, 
  BeginMeasurement, 
  SitRep 
};

const int SLAVE_COMMMAND_STRING_LENGTH = 40;

typedef struct sCmd{

  sInstruct Instruction; 
  char sParam[SLAVE_COMMMAND_STRING_LENGTH];
  int iParam;
  float fParam;

  sCmd& operator = (const volatile sCmd& rhs) volatile{
    this->Instruction = rhs.Instruction;
    this->iParam = rhs.iParam;
    this->fParam = rhs.fParam;

    for (int i = 0; i<SLAVE_COMMMAND_STRING_LENGTH;i++){
      this->sParam[i] = rhs.sParam[i];
    }

  }

  volatile sCmd& operator = (const sCmd& rhs) volatile{
    this->Instruction = rhs.Instruction;
    this->iParam = rhs.iParam;
    this->fParam = rhs.fParam;

    for (int i = 0; i<SLAVE_COMMMAND_STRING_LENGTH;i++){
      this->sParam[i] = rhs.sParam[i];
    }

  }
};

typedef struct mCmd{

  mInstruct Instruction;
  int iParam;
  float fParam;

  // mCmd(const mCmd& rhs){
  //   this->Instruction = rhs.Instruction;
  //   this->iParam = rhs.iParam;
  //   this->fParam = rhs.fParam;
  // }

  mCmd(mInstruct Instruct,int i, float f){
    this->Instruction = Instruct;
    this->iParam = i;
    this->fParam = f;
  }

  mCmd(){
    this->Instruction = SitRep;
    this->iParam = 0;
    this->fParam=0.0;
  }

  mCmd(volatile mCmd& rhs){
    this->Instruction = rhs.Instruction;
    this->iParam = rhs.iParam;
    this->fParam = rhs.fParam;
  }

  mCmd& operator = (const volatile mCmd& rhs) volatile{
    this->Instruction = rhs.Instruction;
    this->iParam = rhs.iParam;
    this->fParam = rhs.fParam;
  }

  volatile mCmd& operator = (const mCmd& rhs) volatile{
    this->Instruction = rhs.Instruction;
    this->iParam = rhs.iParam;
    this->fParam = rhs.fParam;
  }
};

const int IDENTITY_SENSOR_NAME_LENGTH = 25;

typedef struct Identity{
  char SensorName[IDENTITY_SENSOR_NAME_LENGTH];
  int sensorID;
  int sensorChipSelect;

  Identity& operator = (const volatile Identity& rhs) volatile
    {
      for (int i =0; i<IDENTITY_SENSOR_NAME_LENGTH; i++){
        this->SensorName[i] = rhs.SensorName[i];
      }

      this->sensorID = rhs.sensorID;

      this->sensorChipSelect = rhs.sensorChipSelect;
    }

    volatile Identity& operator = (const Identity& rhs) volatile
    {
      for (int i =0; i<IDENTITY_SENSOR_NAME_LENGTH; i++){
        this->SensorName[i] = rhs.SensorName[i];
      }

      this->sensorID = rhs.sensorID;

      this->sensorChipSelect = rhs.sensorChipSelect;
    }
};

const int NUMBER_OF_DATA_ROWS = 3;
const int ROW_HEADING_LENGTH = 10;
const int ROW_UNIT_LENGTH = 5;
const int DATA_ROW_LENGTH = 64;

typedef struct Data{
  int NumColumns[NUMBER_OF_DATA_ROWS];
  int NumRows;
  char RowHeadings[NUMBER_OF_DATA_ROWS][ROW_HEADING_LENGTH];
  char rowUnits[NUMBER_OF_DATA_ROWS][ROW_UNIT_LENGTH];
  float DataPoints[NUMBER_OF_DATA_ROWS][DATA_ROW_LENGTH];

  Data& operator = (const volatile Data& rhs) volatile
    {
      this->NumRows = rhs.NumRows;

      for (int i = 0; i<NUMBER_OF_DATA_ROWS; i++){
        this->NumColumns[i] = rhs.NumColumns[i];

        for(int j = 0; j<ROW_HEADING_LENGTH; j++){
          this->RowHeadings[i][j] = rhs.RowHeadings[i][j];
        }

        for(int j = 0; j<ROW_UNIT_LENGTH; j++){
          this->rowUnits[i][j] = rhs.rowUnits[i][j];
        }

        for(int j = 0; j<DATA_ROW_LENGTH; j++){
          this->DataPoints[i][j] = rhs.DataPoints[i][j];
        }  

      }
    }

    volatile Data& operator = (const Data& rhs) volatile
    {
      this->NumRows = rhs.NumRows;

      for (int i = 0; i<NUMBER_OF_DATA_ROWS; i++){
        this->NumColumns[i] = rhs.NumColumns[i];

        for(int j = 0; j<ROW_HEADING_LENGTH; j++){
          this->RowHeadings[i][j] = rhs.RowHeadings[i][j];
        }

        for(int j = 0; j<ROW_UNIT_LENGTH; j++){
          this->rowUnits[i][j] = rhs.rowUnits[i][j];
        }

        for(int j = 0; j<DATA_ROW_LENGTH; j++){
          this->DataPoints[i][j] = rhs.DataPoints[i][j];
        }  

      }
    }
};

typedef enum MeasurementVectors{
    First,
    Second,
    Third
};

#endif
````

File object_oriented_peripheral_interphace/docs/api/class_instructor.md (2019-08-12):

# Class Instructor

[**Class List**](annotated.md) **>** [**Instructor**](class_instructor.md)

_A class which models a Sensor/peripheral as entity which can issue instructions to the master._ [More...](#detailed-description)

* `#include <Instructor.h>`

Inherited by the following classes: [Sensor](class_sensor.md)

## Public Functions

| Type | Name |
| ---: | :--- |
| | [**Instructor**](class_instructor.md#function-instructor) (const int ChipSelect) <br>_Constructor._  |
|  float | [**getCurrentCommandFloat**](class_instructor.md#function-getcurrentcommandfloat) (void) <br>_Returns the float which qualifies the instruction currently loaded into local memory as issued by the_ [_**Sensor**_](class_sensor.md) _._ |
|  [**sInstruct**](_s_p_i___instruction_set_8h.md#enum-sinstruct) | [**getCurrentCommandInstruction**](class_instructor.md#function-getcurrentcommandinstruction) (void) <br>_Returns the sinstruct object which defines the instruction currently loaded into local memory as issued by the_ [_**Sensor**_](class_sensor.md) _._ |
|  int | [**getCurrentCommandInt**](class_instructor.md#function-getcurrentcommandint) (void) <br>_Returns the integer which qualifies the instruction currently loaded into local memory as issued by the_ [_**Sensor**_](class_sensor.md) _._ |
|  void | [**getCurrentCommandString**](class_instructor.md#function-getcurrentcommandstring) (char Instruction) <br>_Returns the character array which qualifies the instruction currently loaded into local memory as issued by the_ [_**Sensor**_](class_sensor.md) _._ |
|  int | [**howLongShouldIWait**](class_instructor.md#function-howlongshouldiwait) (void) <br>_Asks the sensor how long the master should pause for. Deprecated._  |
|  int | [**howManyInstructions**](class_instructor.md#function-howmanyinstructions) (void) <br>_Asks the_ [_**Sensor**_](class_sensor.md) _how many instructions there are in a measurement cycle._ |
|  void | [**loadNextCommand**](class_instructor.md#function-loadnextcommand) (void) <br>_Fetches the next instruction issued by the sensor in its instruction cycle._  |

# Detailed Description

This class models a peripheral as an entity which can issue commands to the master. The premise is that a sensor peripheral will conduct a measurement by cycling through a number of steps. At each step the sensor may wish for the [**Master**](class_master.md) to perform certain actions, such as display a message to the user, pause for a certain period of time or wait until the user has acknowledged an instruction by button press. In general, the master is expected to iterate through the instruction set, loading an instruction each iteration and repsonding appropriately. i.e. follow the procedure: [**howManyInstructions()**](class_instructor.md#function-howmanyinstructions)-&gt;start loop-&gt;[**loadNextCommand()**](class_instructor.md#function-loadnextcommand)-&gt;React to command-&gt;repeat until all instructions have been processed. 

## Public Functions Documentation

### <a href="#function-instructor" id="function-instructor">function Instructor </a>

```cpp
Instructor::Instructor (
    const int ChipSelect
) 
```

**Parameters:**

* ChipSelect is the Slave Select pin of the SPI peripheral in question. 

### <a href="#function-getcurrentcommandfloat" id="function-getcurrentcommandfloat">function getCurrentCommandFloat </a>

```cpp
float Instructor::getCurrentCommandFloat (
    void
) 
```

The float which qualifies the instruction issued by the sensor is generally used to either augment the information displayed to the user to instruct the master as to how it should carry out the request of the slave. 

### <a href="#function-getcurrentcommandinstruction" id="function-getcurrentcommandinstruction">function getCurrentCommandInstruction </a>

```cpp
sInstruct Instructor::getCurrentCommandInstruction (
    void
) 
```

Elements of the sInstruct type define all the potential instructions which can be issued by a Slave. 

**Returns:**

The instruction issued by the slave. 

### <a href="#function-getcurrentcommandint" id="function-getcurrentcommandint">function getCurrentCommandInt </a>

```cpp
int Instructor::getCurrentCommandInt (
    void
) 
```

The integer which qualifies the instruction issued by the sensor is generally used to either augment the information displayed to the user to instruct the master as to how it should carry out the request of the slave, such as how long to pasue for. 

**Returns:**

The integer which qualifies the instruction. 

### <a href="#function-getcurrentcommandstring" id="function-getcurrentcommandstring">function getCurrentCommandString </a>

```cpp
void Instructor::getCurrentCommandString (
    char Instruction
) 
```

The character array (string) issued by the [**Sensor**](class_sensor.md) is generally intended to be displayed to the user, to update the user on the progress of the measurement procedure or instruct the user on the next step in the measurement procedure, such as inserting the probe into the measurement environment. 

**Parameters:**

* char is the character array into which the instruction string is loaded. 

### <a href="#function-howlongshouldiwait" id="function-howlongshouldiwait">function howLongShouldIWait </a>

```cpp
int Instructor::howLongShouldIWait (
    void
) 
```

**Returns:**

The duration, in milliseconds, the master should pause for. 

### <a href="#function-howmanyinstructions" id="function-howmanyinstructions">function howManyInstructions </a>

```cpp
int Instructor::howManyInstructions (
    void
) 
```

In general, the master is expected to iterate through the instrcution set. 

**Returns:**

The number of instructions in a measurement cycle. 

### <a href="#function-loadnextcommand" id="function-loadnextcommand">function loadNextCommand </a>

```cpp
void Instructor::loadNextCommand (
    void
) 
```

Fetches the next instruction from the [**Sensor**](class_sensor.md) and loads it into local memory. Instructions are issued in the [**sCmd**](structs_cmd.md) type and are therefore consititute an element of the sInstruct instruction set, qualified by a character array (string), integer and float. 

------------------------------
The documentation for this class was generated from the following file `Instructor.h`

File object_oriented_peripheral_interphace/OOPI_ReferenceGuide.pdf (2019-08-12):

## OOPI

Generated by Doxygen 1.8.15

i

1 Hierarchical Index | 1
2 Data Structure Index | 3
3 File Index | 5
4 Data Structure Documentation | 7

Generated by Doxygen

ii

iii

iv

v

5 File Documentation | 59

vi

Index | 79

# Chapter 1

# Hierarchical Index

## 1.1 Class Hierarchy

This inheritance list is sorted roughly, but not completely, alphabetically:

Communicative | | 7
Data | | 11
DataSource | | 13
Sensor | 52
Identifiable | 21
Sensor | 52
Identity | | 24
Instructable | | 26
Sensor | 52
Instructor | 30
Sensor | 52
Master | | 34
mCmd | | 48
sCmd | | 50
UserInstructions | | 56

### 2 Hierarchical Index

# Chapter 2

# Data Structure Index

## 2.1 Data Structures

Here are the data structures with brief descriptions:

Communicative

Data

DataSource

Identifiable

Identity

Instructable

Instructor
A class which models a Sensor/peripheral as entity which can issue instructions to the master 30 Master
A monolithic class to encapsulate and abstract the slave's communication with the master . . . 34 mCmd

sCmd

Sensor

### 4 Data Structure Index

# Chapter 3

# File Index

## 3.1 File List

Here is a list of all files with brief descriptions:

### 6 File Index

# Chapter 4

# Data Structure Documentation

## 4.1 Communicative Class Reference

A class to manage communication with slave module.

#include <Communicative.h>

Public Member Functions

- Communicative (const int CS)

Constructor.
- ∼Communicative (void)

Destructor.
- bool isPeripheralConnected (void)

Checks whether Slave is connected.
- sCmd RequestReply (const mCmd)

Performs a complete transaction; expects Slave to Reply with sCmd object.
- Identity RequestIdentity (const mCmd)

Performs a complete transaction; expects Slave to Reply with Identity object.
- Data RequestData (const mCmd)

Performs a complete transaction; expects Slave to Reply with a Data object.

### 4.1.1 Detailed Description

A class to manage communication with slave module.

This class is designed for SPI communication with a slave device. The class responsibilities include both SPI initialisation and fundamental transactions. The transaction protocol implemented follows the following flow: Clear SS -> Send '?' to slave -> recieve 'ACK' (0x06) from slave -> send request mCmd -> recieve sCmd/Data/Identity as expected -> set SS. Where mCmd, sCmd, Data and Identity are structures defined as types.

### 4.1.2 Constructor & Destructor Documentation

### 8 Data Structure Documentation

### 4.1.2.1 Communicative()

Communicative (

const int CS )

Constructor.

Constructor initialises the SS pin to be used in communications and initialises SPI as Master.

Parameters

CS is the Slave Select pin designation; most commonly PA4.

See also

SPISetup()

4.1.2.2 ∼Communicative()

∼Communicative (

void )

Destructor.

Executes SPI.end();

### 4.1.3 Member Function Documentation

### 4.1.3.1 isPeripheralConnected()

bool isPeripheralConnected (

void )

Checks whether Slave is connected.

Executes a nop transaction.

Returns

true if handshake is successful and Slave responds to '?' with 'ACK'

4.1 Communicative Class Reference | 9

See also

areYouAlive()

Here is the caller graph for this function:

isPeripheralConnected

Identifiable::Identifiable

Instructable::areYouConnected

### 4.1.3.2 RequestData()

Data RequestData (

const mCmd Request )

Performs a complete transaction; expects Slave to Reply with a Data object.

Executes a complete transaction: Clear SS -> Send '?' to slave -> recieve 'ACK' (0x06) from slave -> send request mCmd -> recieve Data -> set SS.

Parameters

mCmd is the mCmd object which constitutes the Request made to the slave.

Returns

The Data object generated by the Slave containing a two dimensional array of data points and the length, headings and units of the data array rows.

See also

RequestReply(), RequestIdentity()

Here is the caller graph for this function:

DataSource::loadData | RequestData Generated by Doxygen

### 10 Data Structure Documentation

### 4.1.3.3 RequestIdentity()

Identity RequestIdentity (

const mCmd Request )

Performs a complete transaction; expects Slave to Reply with Identity object.

Executes a complete transaction: Clear SS -> Send '?' to slave -> recieve 'ACK' (0x06) from slave -> send request mCmd -> recieve Identity -> set SS.

Parameters

mCmd is the mCmd object which constitutes the Request made to the slave.

Returns

The Idenity object generated by the Slave containing the Slave ID and name.

See also

RequestReply(), RequestData()

Here is the caller graph for this function:

RequestIdentity

Identifiable::hasIdentity
Changed
Identifiable::Identifiable | Identifiable::updateIdentity

### 4.1.3.4 RequestReply()

sCmd RequestReply (

const mCmd Request )

Performs a complete transaction; expects Slave to Reply with sCmd object.

Executes a complete transaction: Clear SS -> Send '?' to slave -> recieve 'ACK' (0x06) from slave -> send request mCmd -> recieve sCmd -> set SS.

4.2 Data Struct Reference | 11

Parameters

mCmd is the mCmd object which constitutes the Request made to the slave.

Returns

The sCmd object generated by the Slave as the reply to the request.

See also

RequestIdentity(), RequestData()

Here is the caller graph for this function:

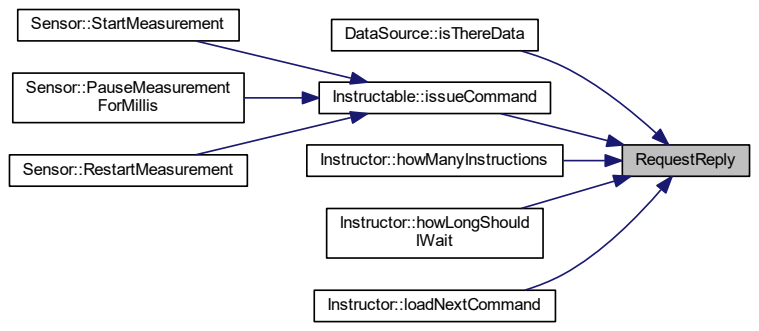
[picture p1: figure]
RequestReply; DataSource::isThereData; Instructable::issueCommand; Instructor::howManyInstructions; Instructor::howLongShould IWait; Instructor::loadNextCommand; Sensor::StartMeasurement; Sensor::PauseMeasurement ForMillis; Sensor::RestartMeasurement

The documentation for this class was generated from the following files:

- Communicative.h
- Communicative.cpp

## 4.2 Data Struct Reference

Type used to encapsulate the data collected by the slave.

#include <SPI_InstructionSet.h>

Public Member Functions

- Data & operator= (const volatile Data &rhs) volatile
- volatile Data & operator= (const Data &rhs) volatile

### 12 Data Structure Documentation

Data Fields

- int NumColumns [NUMBER_OF_DATA_ROWS]

Number of data points currently stored in each row.
- int NumRows

Number of rows. Defined at compilation.
- char RowHeadings [NUMBER_OF_DATA_ROWS][ROW_HEADING_LENGTH]

String headings to describe the data in each row.
- char rowUnits [NUMBER_OF_DATA_ROWS][ROW_UNIT_LENGTH]

String units to qualify the data in each row.
- float DataPoints [NUMBER_OF_DATA_ROWS][DATA_ROW_LENGTH]

Two dimensional array of data. Each row generally treated as an independent vector.

### 4.2.1 Detailed Description

Type used to encapsulate the data collected by the slave.

Data is contained in a two dimensional array but generally modelled as a collection of 'vectors' or rows of data. Each row is allowed a variable number of data points, a string heading and a string unit.

### 4.2.2 Member Function Documentation

### 4.2.2.1 operator=() [1/2]

Data& operator= (

const volatile Data & rhs ) volatile [inline]

### 4.2.2.2 operator=() [2/2]

volatile Data& operator= (

const Data & rhs ) volatile [inline]

### 4.2.3 Field Documentation

### 4.2.3.1 DataPoints

float DataPoints[NUMBER_OF_DATA_ROWS][DATA_ROW_LENGTH]

Two dimensional array of data. Each row generally treated as an independent vector.

4.3 DataSource Class Reference | 13

### 4.2.3.2 NumColumns

int NumColumns[NUMBER_OF_DATA_ROWS]

Number of data points currently stored in each row.

### 4.2.3.3 NumRows

int NumRows

Number of rows. Defined at compilation.

### 4.2.3.4 RowHeadings

char RowHeadings[NUMBER_OF_DATA_ROWS][ROW_HEADING_LENGTH]

String headings to describe the data in each row.

### 4.2.3.5 rowUnits

char rowUnits[NUMBER_OF_DATA_ROWS][ROW_UNIT_LENGTH]

String units to qualify the data in each row.

The documentation for this struct was generated from the following file:

- SPI_InstructionSet.h

## 4.3 DataSource Class Reference

A class which models a Sensor/peripheral as an entity which is a source of data.

#include <DataSource.h>

Inheritance diagram for DataSource:

### DataSource

Sensor Generated by Doxygen

### 14 Data Structure Documentation

Public Member Functions

- DataSource (const int ChipSelect)

Constructor.
- bool isThereData (void)

Asks Sensor/peripheral whether there is Data ready to be collected.
- Data loadData (void)

Loads Data from the Sensor.
- int getNumberOfDataColumns (const MeasurementVectors VectorNumber)

Gets the number of data points along a particular row of the data array.
- int getNumberOfDataRows (void)

Gets the number of rows used in the data array.
- void getRowHeadings (char[NUMBER_OF_DATA_ROWS][ROW_HEADING_LENGTH])

Gets string headings of all the vectors in the data array.
- void getRowUnits (char[NUMBER_OF_DATA_ROWS][ROW_UNIT_LENGTH])

Gets string units of all the vectors in the data array.
- void getDataArray (float[NUMBER_OF_DATA_ROWS][DATA_ROW_LENGTH])

Gets the entire data array.
- void getDataVector (const MeasurementVectors VectorNumber, float[DATA_ROW_LENGTH])

Gets the indicated data vector.
- int getVectorLength (const MeasurementVectors VectorNumber)

Gets the indicated data vector length.
- void getVectorHeading (const MeasurementVectors VectorNumber, char[ROW_HEADING_LENGTH])

Gets the string heading for the vector in question.
- void getVectorUnits (const MeasurementVectors VectorNumber, char[ROW_UNIT_LENGTH])

Gets the string units for the vector in question.
- float getValueOne (void)

Gets the first data point in the first vector.
- float getValueTwo (void)

Gets the second data point in the first vector.
- float getValueThree (void)

Gets the third data point in the first vector.

### 4.3.1 Detailed Description

A class which models a Sensor/peripheral as an entity which is a source of data.

This class models a Sensor as a source of data. The convention in use is that any Sensor can store data such that it occupies a two dimensional float array with maximum dimensions NUMBER_OF_DATA_ROWS x DATA_RO←-W_LENGTH. The data can either be treated as a square array, the dimensions of which can be requested, or as a series of 'vectors', the length of which can be requested.

### 4.3.2 Constructor & Destructor Documentation

### 4.3.2.1 DataSource()

DataSource (

const int ChipSelect )

Constructor.

4.3 DataSource Class Reference | 15

Parameters

ChipSelect is the Slave Select pin of the SPI peripheral in question.

### 4.3.3 Member Function Documentation

### 4.3.3.1 getDataArray()

void getDataArray (

float DataVals[NUMBER_OF_DATA_ROWS][DATA_ROW_LENGTH] )

Gets the entire data array.

Retrieves the entire two dimensionsal data array, irrespective of which elements/vectors are actually in use.

Parameters

float is the array into which the data is written.

See also

Data

### 4.3.3.2 getDataVector()

void getDataVector (

const MeasurementVectors VectorNumber,

float DataVect[DATA_ROW_LENGTH] )

Gets the indicated data vector.

Retrieves a singel row in the two dimesnional data array.

Parameters

VectorNumber | is the row in the data array to be retrieved.
float | is the floating point array into which the data points will be written.

See also

Data, MeasurementVectors

### 16 Data Structure Documentation

### 4.3.3.3 getNumberOfDataColumns()

int getNumberOfDataColumns (

const MeasurementVectors VectorNumber )

Gets the number of data points along a particular row of the data array.

Parameters

VectorNumber is an enumerated type referring to the row in the two dimensional data array.

Returns

The number of data points along a particular row/vector.

See also

MeasurementVectors, Data

### 4.3.3.4 getNumberOfDataRows()

int getNumberOfDataRows (

void )

Gets the number of rows used in the data array.

Returns the number of 'vectors' (rows) which the sensor has used to store data. Ideally, one should utilise the result of this function to iterate through the vectors.

Returns

The number of vectors in use.

See also

Data

### 4.3.3.5 getRowHeadings()

void getRowHeadings (

char Headings[NUMBER_OF_DATA_ROWS][ROW_HEADING_LENGTH] )

Gets string headings of all the vectors in the data array.

Each vector/row is assigned a heading to describe the nature of the data contained within that vector. Such as "Ambient Temperature".

4.3 DataSource Class Reference | 17

Parameters

char is the array of character arrays into which the headings are loaded.

See also

Data

### 4.3.3.6 getRowUnits()

void getRowUnits (

char Units[NUMBER_OF_DATA_ROWS][ROW_UNIT_LENGTH] )

Gets string units of all the vectors in the data array.

Each vector/row is assigned a Units string to define the units of the data contained within that vector. Such as "V" or "Amperes".

Parameters

char is the array of character arrays into which the units are loaded.

See also

Data

### 4.3.3.7 getValueOne()

float getValueOne (

void )

Gets the first data point in the first vector.

Returns

The first data point in the first vector. DataArray[0][0].

See also

Data, MeasurementVectors

### 18 Data Structure Documentation

### 4.3.3.8 getValueThree()

float getValueThree (

void )

Gets the third data point in the first vector.

Returns

The third data point in the first vector. DataArray[2][0].

See also

Data, MeasurementVectors

### 4.3.3.9 getValueTwo()

float getValueTwo (

void )

Gets the second data point in the first vector.

Returns

The second data point in the first vector. DataArray[1][0].

See also

Data, MeasurementVectors

### 4.3.3.10 getVectorHeading()

void getVectorHeading (

const MeasurementVectors VectorNumber,

char Heading[ROW_HEADING_LENGTH] )

Gets the string heading for the vector in question.

Parameters

VectorNumber is the row in the data array to which the heading coresponds.

4.3 DataSource Class Reference | 19

See also

getRowHeadings(), Data, MeasurementVectors

### 4.3.3.11 getVectorLength()

int getVectorLength (

const MeasurementVectors VectorNumber )

Gets the indicated data vector length.

The data vectors (rows) have a max length of DATA_ROW_LENGTH and the Sensor will push data points into said vector. As the Sensor may not utilise the entire width of the data array, the length indicates the number of values which the Sensor has pushed into the vector in question.

Parameters

VectorNumber is the row in the data array.

See also

Data, MeasurementVectors

### 4.3.3.12 getVectorUnits()

void getVectorUnits (

const MeasurementVectors VectorNumber,

char Units[ROW_UNIT_LENGTH] )

Gets the string units for the vector in question.

Parameters

VectorNumber is the row in the data array to which the heading coresponds.

See also

getRowUnits(), Data, MeasurementVectors

### 4.3.3.13 isThereData()

bool isThereData (

void )

### 20 Data Structure Documentation

Asks Sensor/peripheral whether there is Data ready to be collected.

Asks the sensor whether the data is ready to be retrieved by the master. Slave's are, however, required to instantiate a Data object and so premature loads thereof will not fail.

Returns

True if the data is ready to be collected from the Sensor.

Here is the call graph for this function:

isThereData | Communicative::RequestReply

### 4.3.3.14 loadData()

Data loadData (

void )

Loads Data from the Sensor.

Loads the Data object from the Sensor into local memory.

Returns

The Data object loaded into local memory. User of accessors preffered.

See also

getNumberOfDataColumns(), getNumberOfDataRows(), getRowHeadings(), getRowUnits(), getDataArray(), getDataVector(), getVectorLength(), getVectorHeading(),getVectorUnits(), getValueOne(),getValueTwo(),getValueThree()

Here is the call graph for this function:

loadData | Communicative::RequestData

The documentation for this class was generated from the following files:

- DataSource.h
- DataSource.cpp

4.4 Identifiable Class Reference | 21

## 4.4 Identifiable Class Reference

A class which models a Sensor/peripheral as an identifiable entity.

#include <Identifiable.h>

Inheritance diagram for Identifiable:

### Identifiable

### Sensor

Public Member Functions

- Identifiable (const int ChipSelect)

A constructor.
- bool hasIdentityChanged (void)

Checks to seee whether the Identity in local memory is different to the Identity advertised by peripheral.
- void updateIdentity (void)

Loads the Identity advertised by the peripheral into local memory.
- int getIDNumber (void)

Gets the identity number of the attached peripheral.
- void getSensorName (char name[IDENTITY_SENSOR_NAME_LENGTH])

Gets the sensor name of the attached peripheral.

### 4.4.1 Detailed Description

A class which models a Sensor/peripheral as an identifiable entity.

This class models a peripheral as an identifiable entity with ID number and string name. The class allows for the identity to be loaded from the peripheral and interrogated.

### 4.4.2 Constructor & Destructor Documentation

### 4.4.2.1 Identifiable()

Identifiable (

const int ChipSelect )

A constructor.

Constructor for class which loads the identity of any connected SPI peripheral into local memory.

### 22 Data Structure Documentation

Parameters

The Slave Select pin of the SPI peripheral in question.

See also

updateIdentity.

Here is the call graph for this function:

Identifiable

Communicative::isPeripheral
Connected
updateIdentity | Communicative::RequestIdentity

### 4.4.3 Member Function Documentation

### 4.4.3.1 getIDNumber()

int getIDNumber (

void )

Gets the identity number of the attached peripheral.

Reports the identity number of the peripheral currently stored in local memory.

Returns

The sensor ID number.

### 4.4.3.2 getSensorName()

void getSensorName (

char name[IDENTITY_SENSOR_NAME_LENGTH] )

Gets the sensor name of the attached peripheral.

Reports the sensor name of the peripheral currently stored in local memory.

4.4 Identifiable Class Reference | 23

Parameters

name is the character array into which the sensor name is loaded.

### 4.4.3.3 hasIdentityChanged()

bool hasIdentityChanged (

void )

Checks to seee whether the Identity in local memory is different to the Identity advertised by peripheral.

Returns

True if the stored Identity is different than the Identity advertised by the peripheral.

See also

Identity

Here is the call graph for this function:

hasIdentityChanged | Communicative::RequestIdentity

### 4.4.3.4 updateIdentity()

void updateIdentity (

void )

Loads the Identity advertised by the peripheral into local memory.

Here is the call graph for this function:

updateIdentity | Communicative::RequestIdentity Generated by Doxygen

### 24 Data Structure Documentation

Here is the caller graph for this function:

Identifiable | updateIdentity

The documentation for this class was generated from the following files:

- Identifiable.h
- Identifiable.cpp

## 4.5 Identity Struct Reference

Type used to convey the Slave identity.

#include <SPI_InstructionSet.h>

Public Member Functions

- Identity & operator= (const volatile Identity &rhs) volatile
- volatile Identity & operator= (const Identity &rhs) volatile

Data Fields

- char SensorName [IDENTITY_SENSOR_NAME_LENGTH]

String name of the slave. Used for informative reporting to user.
- int sensorID

Single byte identitfication number.
- int sensorChipSelect

SPI chip select of the peripheral in question. Used by slave, but used by Master.

### 4.5.1 Detailed Description

Type used to convey the Slave identity.

### 4.5.2 Member Function Documentation

4.5 Identity Struct Reference | 25

### 4.5.2.1 operator=() [1/2]

Identity& operator= (

const volatile Identity & rhs ) volatile [inline]

### 4.5.2.2 operator=() [2/2]

volatile Identity& operator= (

const Identity & rhs ) volatile [inline]

### 4.5.3 Field Documentation

### 4.5.3.1 sensorChipSelect

int sensorChipSelect

SPI chip select of the peripheral in question. Used by slave, but used by Master.

### 4.5.3.2 sensorID

int sensorID

Single byte identitfication number.

### 4.5.3.3 SensorName

char SensorName[IDENTITY_SENSOR_NAME_LENGTH]

String name of the slave. Used for informative reporting to user.

The documentation for this struct was generated from the following file:

- SPI_InstructionSet.h

### 26 Data Structure Documentation

## 4.6 Instructable Class Reference

A class which models a Sensor/peripheral as entity which can recieve commands.

#include <Instructable.h>

Inheritance diagram for Instructable:

### Instructable

### Sensor

Public Member Functions

- Instructable (const int ChipSelect)

A constructor.
- bool issueCommand (mInstruct)

Issues a command to the peripheral.
- bool issueCommand (mInstruct, int)

Issues a command to the peripheral.
- bool issueCommand (mInstruct, float)

Issues a command to the peripheral.
- bool issueCommand (mInstruct, int, float)

Issues a command to the peripheral.
- bool areYouConnected (void)

Checks to see whether the peripheral is connected.

### 4.6.1 Detailed Description

A class which models a Sensor/peripheral as entity which can recieve commands.

This class models a peripheral as an entity which can be issued commands. The commands issued are elements of the set defined by the mInstruct type. Each instruction can be accompanied by and integer and/or float as required to act as parameters to qualify the command. For example, if the peripheral is commanded to pause for an interval, the integer parameter is used by the peripheral to determine the length of time for which to pause.

### 4.6.2 Constructor & Destructor Documentation

### 4.6.2.1 Instructable()

Instructable (

const int ChipSelect )

A constructor.

4.6 Instructable Class Reference | 27

Parameters

The Slave Select pin of the SPI peripheral in question.

### 4.6.3 Member Function Documentation

### 4.6.3.1 areYouConnected()

bool areYouConnected (

void )

Checks to see whether the peripheral is connected.

Initiates handshake and nop transaction with the sensor to ensure that it is connected and responding appropriately.

Returns

True if the peripheral is connected and communicating effectively.

Here is the call graph for this function:

areYouConnected | Communicative::isPeripheral Connected

### 4.6.3.2 issueCommand() [1/4]

bool issueCommand (

mInstruct Command )

Issues a command to the peripheral.

Sends a command which is an element of the mInstruct type.

Parameters

mInstruct is the command issued to the peripheral.

### 28 Data Structure Documentation

Returns

True if the peripheral acknowledges the command.

Here is the call graph for this function:

issueCommand | Communicative::RequestReply

Here is the caller graph for this function:

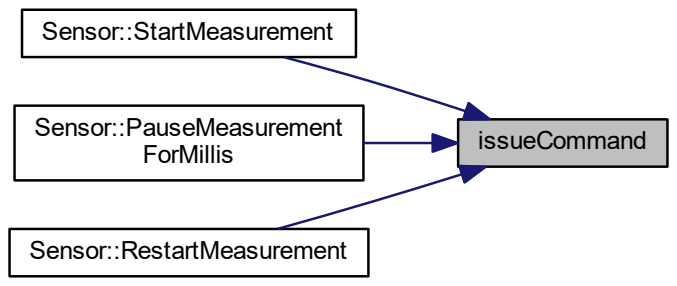
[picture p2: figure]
issueCommand; Sensor::StartMeasurement; Sensor::PauseMeasurement ForMillis; Sensor::RestartMeasurement

### 4.6.3.3 issueCommand() [2/4]

bool issueCommand (

mInstruct Command,

int intParam )

Issues a command to the peripheral.

Sends a command which is an element of the mInstruct type qualified by an integer parameter (generally used to instruct on wait time or similar).

Parameters

mInstruct is the command issued to the peripheral and int is the integer qualifier.

4.6 Instructable Class Reference | 29

Returns

True if the peripheral acknowledges the command.

Here is the call graph for this function:

issueCommand | Communicative::RequestReply

### 4.6.3.4 issueCommand() [3/4]

bool issueCommand (

mInstruct Command,

float floatParam )

Issues a command to the peripheral.

Sends a command which is an element of the mInstruct type qualified by a float parameter.

Parameters

mInstruct is the command issued to the peripheral and float is the floating point qualifier.

Returns

True if the peripheral acknowledges the command.

Here is the call graph for this function:

issueCommand | Communicative::RequestReply Generated by Doxygen

### 30 Data Structure Documentation

### 4.6.3.5 issueCommand() [4/4]

bool issueCommand (

mInstruct Command,

int intParam,

float floatParam )

Issues a command to the peripheral.

Sends a command which is an element of the mInstruct type qualified by an integer parameter (generally used to instruct on wait time or similar) and a floating point parameter.

Parameters

mInstruct is the command issued to the peripheral, int is the integer qualifier and float is the floating point qualifier.

Returns

True if the peripheral acknowledges the command.

Here is the call graph for this function:

issueCommand | Communicative::RequestReply

The documentation for this class was generated from the following files:

- Instructable.h
- Instructable.cpp

## 4.7 Instructor Class Reference

A class which models a Sensor/peripheral as entity which can issue instructions to the master.

#include <Instructor.h>

4.7 Instructor Class Reference | 31

Inheritance diagram for Instructor:

### Instructor

### Sensor

Public Member Functions

- Instructor (const int ChipSelect)

Constructor.
- int howManyInstructions (void)

Asks the Sensor how many instructions there are in a measurement cycle.
- int howLongShouldIWait (void)

Asks the sensor how long the master should pause for. Deprecated.
- void loadNextCommand (void)

Fetches the next instruction issued by the sensor in its instruction cycle.
- void getCurrentCommandString (char[SLAVE_COMMMAND_STRING_LENGTH])

Returns the character array which qualifies the instruction currently loaded into local memory as issued by the Sensor.
- int getCurrentCommandInt (void)

Returns the integer which qualifies the instruction currently loaded into local memory as issued by the Sensor.
- float getCurrentCommandFloat (void)

Returns the float which qualifies the instruction currently loaded into local memory as issued by the Sensor.
- sInstruct getCurrentCommandInstruction (void)

Returns the sinstruct object which defines the instruction currently loaded into local memory as issued by the Sensor.

### 4.7.1 Detailed Description

A class which models a Sensor/peripheral as entity which can issue instructions to the master.

This class models a peripheral as an entity which can issue commands to the master. The premise is that a sensor peripheral will conduct a measurement by cycling through a number of steps. At each step the sensor may wish for the Master to perform certain actions, such as display a message to the user, pause for a certain period of time or wait until the user has acknowledged an instruction by button press. In general, the master is expected to iterate through the instruction set, loading an instruction each iteration and repsonding appropriately. i.e. follow the procedure: howManyInstructions()->start loop->loadNextCommand()->React to command->repeat until all instructions have been processed.

### 4.7.2 Constructor & Destructor Documentation

### 32 Data Structure Documentation

### 4.7.2.1 Instructor()

Instructor (

const int ChipSelect )

Constructor.

Parameters

ChipSelect is the Slave Select pin of the SPI peripheral in question.

### 4.7.3 Member Function Documentation

### 4.7.3.1 getCurrentCommandFloat()

float getCurrentCommandFloat (

void )

Returns the float which qualifies the instruction currently loaded into local memory as issued by the Sensor.

The float which qualifies the instruction issued by the sensor is generally used to either augment the information displayed to the user to instruct the master as to how it should carry out the request of the slave.

### 4.7.3.2 getCurrentCommandInstruction()

sInstruct getCurrentCommandInstruction (

void )

Returns the sinstruct object which defines the instruction currently loaded into local memory as issued by the Sensor.

Elements of the sInstruct type define all the potential instructions which can be issued by a Slave.

Returns

The instruction issued by the slave.

### 4.7.3.3 getCurrentCommandInt()

int getCurrentCommandInt (

void )

Returns the integer which qualifies the instruction currently loaded into local memory as issued by the Sensor.

The integer which qualifies the instruction issued by the sensor is generally used to either augment the information displayed to the user to instruct the master as to how it should carry out the request of the slave, such as how long to pasue for.

Returns

The integer which qualifies the instruction.

4.7 Instructor Class Reference | 33

### 4.7.3.4 getCurrentCommandString()

void getCurrentCommandString (

char Instruction[SLAVE_COMMMAND_STRING_LENGTH] )

Returns the character array which qualifies the instruction currently loaded into local memory as issued by the Sensor.

The character array (string) issued by the Sensor is generally intended to be displayed to the user, to update the user on the progress of the measurement procedure or instruct the user on the next step in the measurement procedure, such as inserting the probe into the measurement environment.

Parameters

char is the character array into which the instruction string is loaded.

### 4.7.3.5 howLongShouldIWait()

int howLongShouldIWait (

void )

Asks the sensor how long the master should pause for. Deprecated.

Returns

The duration, in milliseconds, the master should pause for.

Here is the call graph for this function:

howLongShouldIWait | Communicative::RequestReply

### 4.7.3.6 howManyInstructions()

int howManyInstructions (

void )

Asks the Sensor how many instructions there are in a measurement cycle.

In general, the master is expected to iterate through the instrcution set.

### 34 Data Structure Documentation

Returns

The number of instructions in a measurement cycle.

Here is the call graph for this function:

howManyInstructions | Communicative::RequestReply

### 4.7.3.7 loadNextCommand()

void loadNextCommand (

void )

Fetches the next instruction issued by the sensor in its instruction cycle.

Fetches the next instruction from the Sensor and loads it into local memory. Instructions are issued in the sCmd type and are therefore consititute an element of the sInstruct instruction set, qualified by a character array (string), integer and float. Here is the call graph for this function:

loadNextCommand | Communicative::RequestReply

The documentation for this class was generated from the following files:

- Instructor.h
- Instructor.cpp

## 4.8 Master Class Reference

A monolithic class to encapsulate and abstract the slave's communication with the master.

#include <Master.h>

4.8 Master Class Reference | 35

Public Member Functions

- Master (const int SensorIDNumber, const char SensorName[ ], const char InstructionSet[ ][SLAVE_COMMMAND_STRING_LENGTH], const int NumberOfInstructions, const sInstruct MasterInstructionSet[ ], const int intParams[ ], const float
floatParams[ ])
- Master (void)
- ∼Master (void)
- Master (volatile const Master &)
- volatile Master & operator= (const Master &rhs) volatile
- volatile Master & operator= (volatile const Master &rhs) volatile
- void SETUP (const int SensorIDNumber, volatile char SensorName[ ], volatile char Instruction←-Set[ ][SLAVE_COMMMAND_STRING_LENGTH], const int NumberOfInstructions, volatile sInstruct Master←-InstructionSet[ ], volatile int intParams[ ], volatile float floatParams[ ]) volatile

Set up of the commuication mechanism.
- void SPISetup (void) volatile

Sets up SPI and attaches interrupt.
- bool Handshake (void) volatile

Manages the handshake component of any transaction.
- mCmd loadRequest (void) volatile

Retrieve the request sent by the master.
- mInstruct getCurrentInstruction (void) volatile

Returns the mInstruct component of the most recently loaded request sent by the master.
- int getCurrentInstructionIntParameter (void) volatile

Returns the integer parameter of the most recently loaded request sent by the master.
- float getCurrentInstructionFloatParameter (void) volatile

Returns the floating point parameter of the most recently loaded request sent by the master.
- void sendReply (const sCmd Reply) volatile

Send an sCmd object in reply to the request recieved from Master.
- void sendReply (const sInstruct Instruction) volatile

Send a reply to the request recieved from master.
- void sendReply (const sInstruct Instruction, volatile char InstructionString[SLAVE_COMMMAND_STRING_LENGTH]) volatile

Send a reply to the request recieved from master.
- void sendReply (const sInstruct Instruction, const int iParam) volatile

Send a reply to the request recieved from master.
- void sendReply (const sInstruct Instruction, const float fParam) volatile

Send a reply to the request recieved from master.
- void sendReply (const sInstruct Instruction, const int iParam, const int fParam) volatile

Send a reply to the request recieved from master.
- void sendReply (sInstruct Instruction, int iParam, volatile char InstructionString[SLAVE_COMMMAND_STRING_LENGTH]) volatile

Send a reply to the request recieved from master.
- void sendReply (sInstruct Instruction, float fParam, volatile char InstructionString[SLAVE_COMMMAND_STRING_LENGTH])
volatile

Send a reply to the request recieved from master.
- void sendReply (sInstruct Instruction, int iParam, float fParam, volatile char InstructionString[SLAVE_COMMMAND_STRING_LENGTH]) volatile

Send a reply to the request recieved from master.
- void sendData (void) volatile

Sends the local Data object to the master in reply to appropriate request.
- void sendIdentity (void) volatile

Sends slave Identity object to the master in reply to appropriate request.

### 36 Data Structure Documentation

- bool PushMeasurementVector (const MeasurementVectors VectorNumber, const float Measurement) volatile

Pushes a data point onto one of the data vectors.
- bool PopMeasurementVector (MeasurementVectors VectorNumber) volatile

Pops a data point from the tail end of a designated vector.
- void ClearMeasurementVector (MeasurementVectors VectorNumber) volatile

Clears all data points from a particular vector.
- void setMeasurementVectorHeading (MeasurementVectors VectorNumber, volatile char Heading[ROW_HEADING_LENGTH]) volatile

Sets the string heading assigned to a paritcular data vector.
- void setMeasurementVectorUnits (MeasurementVectors VectorNumber, volatile char Units[ROW_UNIT_LENGTH]) volatile

Sets the string Units assigned to a paritcular data vector.
- bool isThereData (void) volatile

Checks to see whether any data has been pushed to any of the data vectors locally.
- void sendTotalNumOfInstructions (void) volatile

Sends a reply to Master specifiying the total number of instructions in a measurement procedure.
- int getCurrentInstructionNumber (void) volatile

Gets the value of the counter which tracks the current instruction number throughout the measurement procedure.
- bool sendNextUserInstruction (void) volatile

Sends the next instruction in the measurement cycle to the master.
- void resendCurrentUserInstruction (void) volatile

Resends the cuurent instruction in the measurement procedure to the master.
- void restartUserInstructionCycle (void) volatile

Restarts the measurement prcedure.
- void beginMeasurement (void) volatile

Updates state to indicate that Master has requested the intitiation of the measurement procedure.
- bool shallIStart (void) volatile

Checks whether the beginMeasurement() method has been called.

### 4.8.1 Detailed Description

A monolithic class to encapsulate and abstract the slave's communication with the master.

A single transaction is characterised by the following flow of control: Clear SS -> Enter IRQ -> Recieve '?' from master -> send 'ACK' (0x06) to master -> recieve request mCmd -> send sCmd/Data/Identity as expected -> exit IRQ. Where mCmd, sCmd, Data and Identity are structures defined as types. The intial Recieve '?' -> send 'ACK' is known as the handshake. This class' responsibilities include intitialising and handling the SPI, attaching the interrupt and providing the IRQ, managing the handshake and encapsulating the reponse mechanism. Note the use of a volatile interface to allow for safe use of the interrupt.

### 4.8.2 Constructor & Destructor Documentation

4.8 Master Class Reference | 37

### 4.8.2.1 Master() [1/3]

Master (

const int SensorIDNumber,

const char SensorName[ ],

const char InstructionSet[ ][SLAVE_COMMMAND_STRING_LENGTH],

const int NumberOfInstructions,

const sInstruct MasterInstructionSet[ ],

const int intParams[ ],

const float floatParams[ ] )

### 4.8.2.2 Master() [2/3]

Master (

void )

4.8.2.3 ∼Master()

∼Master (

void )

### 4.8.2.4 Master() [3/3]

Master (

volatile const Master & rhs )

### 4.8.3 Member Function Documentation

### 4.8.3.1 beginMeasurement()

void beginMeasurement (

void ) volatile

Updates state to indicate that Master has requested the intitiation of the measurement procedure.

Designed to allow the IRQ to update the slave state so that the procedural code in main() can initiate the measurement procedure. Here is the call graph for this function:

beginMeasurement | sendReply Generated by Doxygen

### 38 Data Structure Documentation

### 4.8.3.2 ClearMeasurementVector()

void ClearMeasurementVector (

MeasurementVectors VectorNumber ) volatile

Clears all data points from a particular vector.

Parameters

VectorNumber is the enumerated reference to the row/vector in the data array being accessed.

### 4.8.3.3 getCurrentInstruction()

mInstruct getCurrentInstruction (

void ) volatile

Returns the mInstruct component of the most recently loaded request sent by the master.

### 4.8.3.4 getCurrentInstructionFloatParameter()

float getCurrentInstructionFloatParameter (

void ) volatile

Returns the floating point parameter of the most recently loaded request sent by the master.

### 4.8.3.5 getCurrentInstructionIntParameter()

int getCurrentInstructionIntParameter (

void ) volatile

Returns the integer parameter of the most recently loaded request sent by the master.

### 4.8.3.6 getCurrentInstructionNumber()

int getCurrentInstructionNumber (

void ) volatile

Gets the value of the counter which tracks the current instruction number throughout the measurement procedure.

4.8 Master Class Reference | 39

### 4.8.3.7 Handshake()

bool Handshake (

void ) volatile

Manages the handshake component of any transaction.

Manages the handshake between master and slave; defined by: Recieve '?' -> send 'ACK' (0x06).

Returns

True if the handshake was successful.

Here is the caller graph for this function:

SPI_IRQ | Handshake

### 4.8.3.8 isThereData()

bool isThereData (

void ) volatile

Checks to see whether any data has been pushed to any of the data vectors locally.

Returns

True if any data points exist in the data vectors locally.

### 4.8.3.9 loadRequest()

mCmd loadRequest (

void ) volatile

Retrieve the request sent by the master.

After each handshake, the master will proceed to send a request, defined by an mCmd object. This function must runafter each handshake. This function reassembles the mCmd request sent by the master, byte by byte and stores it in local memory.

### 40 Data Structure Documentation

Returns

the mCmd object sent by the master.

Here is the caller graph for this function:

SPI_IRQ | loadRequest

### 4.8.3.10 operator=() [1/2]

volatile Master& operator= (

const Master & rhs ) volatile [inline]

### 4.8.3.11 operator=() [2/2]

volatile Master& operator= (

volatile const Master & rhs ) volatile [inline]

### 4.8.3.12 PopMeasurementVector()

bool PopMeasurementVector (

MeasurementVectors VectorNumber ) volatile

Pops a data point from the tail end of a designated vector.

Removes the most recent data point from the vector in question by marking said data slot writeable to be the next PushMeasurementVector().

Parameters

VectorNumber is the enumerated reference to the row/vector in the data array being accessed.

Returns

False if the vector/row in question is empty.

4.8 Master Class Reference | 41

### 4.8.3.13 PushMeasurementVector()

bool PushMeasurementVector (

const MeasurementVectors VectorNumber,

const float Measurement ) volatile

Pushes a data point onto one of the data vectors.

Adds a data point to the next available slot in a particular vector until the vector (row) in the data array is full.

Parameters

VectorNumber | is the enumerated reference to the row/vector in the data array being accessed.
Measurement | is the data point to be stored.

Returns

False if the vector/row in question is full. (See DATA_ROW_LENGTH).

### 4.8.3.14 resendCurrentUserInstruction()

void resendCurrentUserInstruction (

void ) volatile

Resends the cuurent instruction in the measurement procedure to the master.

This method will NOT advance the measurement cycle. Here is the call graph for this function:

resendCurrentUserInstruction | sendReply

### 4.8.3.15 restartUserInstructionCycle()

void restartUserInstructionCycle (

void ) volatile

Restarts the measurement prcedure.

Restarts the measuement procedure such that the next instruction sent will be the first instruction in the measurement cycle.

### 42 Data Structure Documentation

### 4.8.3.16 sendData()

void sendData (

void ) volatile

Sends the local Data object to the master in reply to appropriate request.

Sends Data object to the master in reponse to a request made by the master for Data. NOTE: This must be used as the response to the appropriate mInstruct request. In paricular, (mInstruct)SendDataPlease

### 4.8.3.17 sendIdentity()

void sendIdentity (

void ) volatile

Sends slave Identity object to the master in reply to appropriate request.

Sends the slave Identity object in response to an appropriate request made by master. NOTE: This must be used as the response to the appropriate mInstruct request. In paricular, (mInstruct)WhoAreYou

### 4.8.3.18 sendNextUserInstruction()

bool sendNextUserInstruction (

void ) volatile

Sends the next instruction in the measurement cycle to the master.

Sends the next instruction in the measurement cycle array in reponse to the appropriate request from master. Specifically, (mInstruct)NextCommandPlease. This method will auto-advance the measurement cycle to the next instruction and re-define the 'current instruction'.

Returns

False if the final instruction in the measurement procedure has already been sent and the measurement procedure is now complete.

Here is the call graph for this function:

sendNextUserInstruction | sendReply | Generated by Doxygen

4.8 Master Class Reference | 43

### 4.8.3.19 sendReply() [1/9]

void sendReply (

const sCmd Reply ) volatile

Send an sCmd object in reply to the request recieved from Master.

Here is the caller graph for this function:

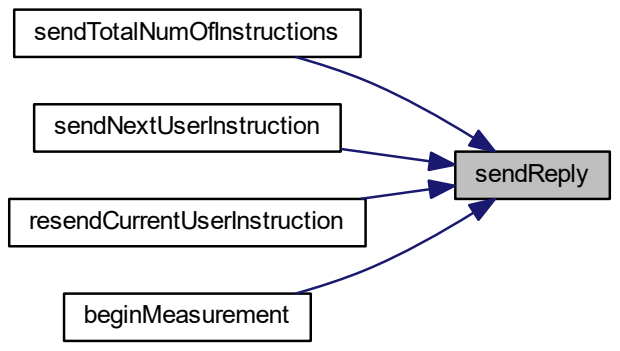
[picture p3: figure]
sendReply; sendTotalNumOfInstructions; sendNextUserInstruction; resendCurrentUserInstruction; beginMeasurement

### 4.8.3.20 sendReply() [2/9]

void sendReply (

const sInstruct Instruction ) volatile

Send a reply to the request recieved from master.

Assembles the sCmd object from the supplied parameters. Overloaded.

### 4.8.3.21 sendReply() [3/9]

void sendReply (

const sInstruct Instruction,

volatile char InstructionString[SLAVE_COMMMAND_STRING_LENGTH] ) volatile

Send a reply to the request recieved from master.

Assembles the sCmd object from the supplied parameters. Overloaded. Note the need for the char∗ to be defined locally as volatile char[]. Cannot pass string literals.

### 44 Data Structure Documentation

### 4.8.3.22 sendReply() [4/9]

void sendReply (

const sInstruct Instruction,

const int iParam ) volatile

Send a reply to the request recieved from master.

Assembles the sCmd object from the supplied parameters. Overloaded.

### 4.8.3.23 sendReply() [5/9]

void sendReply (

const sInstruct Instruction,

const float fParam ) volatile

Send a reply to the request recieved from master.

Assembles the sCmd object from the supplied parameters. Overloaded.

### 4.8.3.24 sendReply() [6/9]

void sendReply (

const sInstruct Instruction,

const int iParam,

const int fParam ) volatile

Send a reply to the request recieved from master.

Assembles the sCmd object from the supplied parameters. Overloaded.

### 4.8.3.25 sendReply() [7/9]

void sendReply (

sInstruct Instruction,

int iParam,

volatile char InstructionString[SLAVE_COMMMAND_STRING_LENGTH] ) volatile

Send a reply to the request recieved from master.

Assembles the sCmd object from the supplied parameters. Overloaded. Note the need for the char∗ to be defined locally as volatile char[]. Cannot pass string literals.

### 4.8.3.26 sendReply() [8/9]

void sendReply (

sInstruct Instruction,

float fParam,

volatile char InstructionString[SLAVE_COMMMAND_STRING_LENGTH] ) volatile

Send a reply to the request recieved from master.

Assembles the sCmd object from the supplied parameters. Overloaded. Note the need for the char∗ to be defined locally as volatile char[]. Cannot pass string literals.

4.8 Master Class Reference | 45

### 4.8.3.27 sendReply() [9/9]

void sendReply (

sInstruct Instruction,

int iParam,

float fParam,

volatile char InstructionString[SLAVE_COMMMAND_STRING_LENGTH] ) volatile

Send a reply to the request recieved from master.

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

### 4.8.3.28 sendTotalNumOfInstructions()

void sendTotalNumOfInstructions (

void ) volatile

Sends a reply to Master specifiying the total number of instructions in a measurement procedure.

Here is the call graph for this function:

sendTotalNumOfInstructions | sendReply

### 4.8.3.29 setMeasurementVectorHeading()

void setMeasurementVectorHeading (

MeasurementVectors VectorNumber,

volatile char Heading[ROW_HEADING_LENGTH] ) volatile

Sets the string heading assigned to a paritcular data vector.

NOTE: The Heading parameter must be declared locally as volatile char[]. Literal strings cannot be passed to this function.

Parameters

VectorNumber | is the enumerated reference to the row/vector in the data array in question.
Heading[ ] | is the character array containing the string heading.

### 46 Data Structure Documentation

### 4.8.3.30 setMeasurementVectorUnits()

void setMeasurementVectorUnits (

MeasurementVectors VectorNumber,

volatile char Units[ROW_UNIT_LENGTH] ) volatile

Sets the string Units assigned to a paritcular data vector.

NOTE: The Units parameter must be declared locally as volatile char[]. Literal strings cannot be passed to this function.

Parameters

VectorNumber | is the enumerated reference to the row/vector in the data array in question.
Units[ ] | is the character array containing the string heading.

### 4.8.3.31 SETUP()

void SETUP (

const int SensorIDNumber,

volatile char SensorName[ ],

volatile char InstructionSet[ ][SLAVE_COMMMAND_STRING_LENGTH],

const int NumberOfInstructions,

volatile sInstruct MasterInstructionSet[ ],

volatile int intParams[ ],

volatile float floatParams[ ] ) volatile

Set up of the commuication mechanism.

Intialised the auto-instantiated Master object, attaches the IRQ and sets up SPI communications.

Parameters

SensorIDNumber | is the identity number of th slave.
SensorName | is the string name of the slave.
InstructionSet | is the array of strings associated with each instruction in the measuremnt cycle. Generally to be displayed to the user.
NumberOfInstructions | is the number of instructions in a single measurement cycle/procedure.
MasterInstructionSet | is the array of sInstruct objects associated with each instruction in the measurement cycle. Defines the required action by the master for each step of the measurement procedure.
IntParams | is the array of integer parameter associated with each instruction.
FloatParams | is the array of floating point parameters accosiated with each instruction.

4.8 Master Class Reference | 47

Here is the call graph for this function:

### 4.8.3.32 shallIStart()

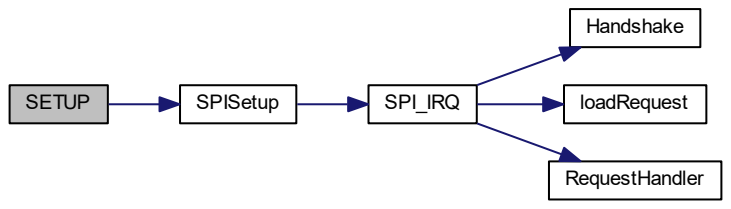
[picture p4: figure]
SETUP; SPISetup; SPI_IRQ; Handshake; loadRequest; RequestHandler

bool shallIStart (

void ) volatile

Checks whether the beginMeasurement() method has been called.

Allows procedural code in main() to determine whether the system state has changed during an interrupt in response to a request by the master to initiate the measurement procedure.

### 4.8.3.33 SPISetup()

void SPISetup (

void ) volatile

Sets up SPI and attaches interrupt.

Here is the call graph for this function:

SPISetup | SPI_IRQ

### Handshake

### loadRequest

RequestHandler Generated by Doxygen

### 48 Data Structure Documentation

Here is the caller graph for this function:

SETUP | SPISetup

The documentation for this class was generated from the following files:

- Master.h
- Master.cpp

## 4.9 mCmd Struct Reference

Type used by master to send requests to slave.

#include <SPI_InstructionSet.h>

Public Member Functions

- mCmd (mInstruct Instruct, int i, float f)
- mCmd ()
- mCmd (volatile mCmd &rhs)
- mCmd & operator= (const volatile mCmd &rhs) volatile
- volatile mCmd & operator= (const mCmd &rhs) volatile

Data Fields

- mInstruct Instruction

Instruction to slave.
- int iParam

Integer paramter which qualifies the instruction.
- float fParam

Floating point parameter which wualifies the instruction.

### 4.9.1 Detailed Description

Type used by master to send requests to slave.

Each transaction, following the initial handshake, the master will send a request and the slave will send a reply. Requests made by the master will always take the form of an mCmd object, which contains a parameterised instance of the instruction set, mInstruct, which defines the class of repsonse expected by the slave.

4.9 mCmd Struct Reference | 49

### 4.9.2 Constructor & Destructor Documentation

### 4.9.2.1 mCmd() [1/3]

mCmd (

mInstruct Instruct,

int i,

float f ) [inline]

### 4.9.2.2 mCmd() [2/3]

mCmd ( ) [inline]

### 4.9.2.3 mCmd() [3/3]

mCmd (

volatile mCmd & rhs ) [inline]

### 4.9.3 Member Function Documentation

### 4.9.3.1 operator=() [1/2]

mCmd& operator= (

const volatile mCmd & rhs ) volatile [inline]

### 4.9.3.2 operator=() [2/2]

volatile mCmd& operator= (

const mCmd & rhs ) volatile [inline]

### 4.9.4 Field Documentation

### 50 Data Structure Documentation

### 4.9.4.1 fParam

float fParam

Floating point parameter which wualifies the instruction.

### 4.9.4.2 Instruction

mInstruct Instruction

Instruction to slave.

Defines the request made of the slave by the master during any transacion. mInstruct defines a finite set of requests which the master can make of the slave.

### 4.9.4.3 iParam

int iParam

Integer paramter which qualifies the instruction.

The documentation for this struct was generated from the following file:

- SPI_InstructionSet.h

## 4.10 sCmd Struct Reference

Type used by slave to send reply to master,.

#include <SPI_InstructionSet.h>

Public Member Functions

- sCmd & operator= (const volatile sCmd &rhs) volatile
- volatile sCmd & operator= (const sCmd &rhs) volatile

Data Fields

- sInstruct Instruction

Instruction to master.
- char sParam [SLAVE_COMMMAND_STRING_LENGTH]

String parameter which qualifies the instruction. Often used to convey instructions which are to be displayed to the user.
- int iParam

Integer parameter which qualifies the instruction.
- float fParam

Floating point parameter which qualifies the instruction.

4.10 sCmd Struct Reference | 51

### 4.10.1 Detailed Description

Type used by slave to send reply to master,.

Each transaction, following the initial handshake, the master will send a request and the slave will send a reply. Replied made by the slave are generally in the form of an sCmd object, which contains a parameterised instance of the slave instruction set, sInstruct, which defines the action which the slave requires the master to carry out. Other acceptable replies to particular requests from the master are Data and Identity objects.

### 4.10.2 Member Function Documentation

### 4.10.2.1 operator=() [1/2]

sCmd& operator= (

const volatile sCmd & rhs ) volatile [inline]

### 4.10.2.2 operator=() [2/2]

volatile sCmd& operator= (

const sCmd & rhs ) volatile [inline]

### 4.10.3 Field Documentation

### 4.10.3.1 fParam

float fParam

Floating point parameter which qualifies the instruction.

### 4.10.3.2 Instruction

sInstruct Instruction

Instruction to master.

Defines the reply made by the slave in repsonse to the request posed by the master during a single transaction. Used to confirm commands issued by the master or issue commands to the master.

### 52 Data Structure Documentation

### 4.10.3.3 iParam

int iParam

Integer parameter which qualifies the instruction.

### 4.10.3.4 sParam

char sParam[SLAVE_COMMMAND_STRING_LENGTH]

String parameter which qualifies the instruction. Often used to convey instructions which are to be displayed to the user.

The documentation for this struct was generated from the following file:

- SPI_InstructionSet.h

## 4.11 Sensor Class Reference

A class which models a Sensor/peripheral.

#include <Sensor.h>

Inheritance diagram for Sensor:

Sensor

Instructable | Instructor | DataSource | Identifiable

Collaboration diagram for Sensor:

Sensor

Instructable | Instructor | DataSource | Identifiable

4.11 Sensor Class Reference | 53

Public Member Functions

- Sensor (const int ChipSelect)

Constructor.
- int StartMeasurement (void)

Instruct the sensor to initiate the measurement procedure.
- int PauseMeasurementForMillis (int)

Instruct the sensor to pause the measurement procedure for a brief period.
- int RestartMeasurement (void)

Instruct the sensor to restart the measurement procedure.

### 4.11.1 Detailed Description

A class which models a Sensor/peripheral.

This class models a sensor peripheral as an entity which has a queriable Identity, is a source of Data, can be issued commands and can issue a series of instructions in turn. In particular, a sensor is considered to perform a measurement procedure consisting of a series of steps; at each step, the sensor will issue instructions to the master to be acted upon and/or displayed to the user. The sensor may also require feedback from the user such as confirmation of the completion of an instruction, before proceeding to the next instruction in the measurement procedure. While the sensor dictates the flow of the measurement procedure, a master reserves the right to initiate the procedure, pause the procedure and restart the procedure.

### 4.11.2 Constructor & Destructor Documentation

### 4.11.2.1 Sensor()

Sensor (

const int ChipSelect )

Constructor.

Parameters

ChipSelect is the Slave Select pin of the SPI peripheral in question.

### 4.11.3 Member Function Documentation

### 4.11.3.1 PauseMeasurementForMillis()

int PauseMeasurementForMillis (

int PauseTime )

### 54 Data Structure Documentation

Instruct the sensor to pause the measurement procedure for a brief period.

Instructs the sensor to temporarily pause the measurement procedure for a period defined in milliseconds.

4.11 Sensor Class Reference | 55

Parameters

int is the number of milliseconds for which the sensor is to pause.

Returns

True if the sensor acknowledges the request.

Here is the call graph for this function:

PauseMeasurementForMillis | Instructable::issueCommand | Communicative::RequestReply

### 4.11.3.2 RestartMeasurement()

int RestartMeasurement (

void )

Instruct the sensor to restart the measurement procedure.

Instructs the sensor to restart the measurement procedure. The sensor will wait revert to its initial state, waiting for a StartMeasurement() command before proceeding to the first instruction in the procedure.

Returns

True if the sensor acknowledges the request.

Here is the call graph for this function:

RestartMeasurement | Instructable::issueCommand | Communicative::RequestReply Generated by Doxygen

### 56 Data Structure Documentation

### 4.11.3.3 StartMeasurement()

int StartMeasurement (

void )

Instruct the sensor to initiate the measurement procedure.

Informs the sensor to start the measurement procedure and proceed to the first instruction step.

Returns

True if the sensor acknowledges the request.

Here is the call graph for this function:

StartMeasurement | Instructable::issueCommand | Communicative::RequestReply

The documentation for this class was generated from the following files:

- Sensor.h
- Sensor.cpp

## 4.12 UserInstructions Struct Reference

#include <Master.h>

Public Member Functions

- UserInstructions & operator= (const volatile UserInstructions &rhs) volatile
- volatile UserInstructions & operator= (const UserInstructions &rhs) volatile

Data Fields

- int NumOfInstructions
- int InstructionCounter
- char InstructionSet [MAX_USER_INSTRUCTION_NUMBER][SLAVE_COMMMAND_STRING_LENGTH]
- sInstruct MasterInstructionSet [MAX_USER_INSTRUCTION_NUMBER]
- int iParams [MAX_USER_INSTRUCTION_NUMBER]
- float fParams [MAX_USER_INSTRUCTION_NUMBER]

### 4.12.1 Member Function Documentation

4.12 UserInstructions Struct Reference | 57

### 4.12.1.1 operator=() [1/2]

UserInstructions& operator= (

const volatile UserInstructions & rhs ) volatile [inline]

### 4.12.1.2 operator=() [2/2]

volatile UserInstructions& operator= (

const UserInstructions & rhs ) volatile [inline]

### 4.12.2 Field Documentation

### 4.12.2.1 fParams

float fParams[MAX_USER_INSTRUCTION_NUMBER]

### 4.12.2.2 InstructionCounter

int InstructionCounter

### 4.12.2.3 InstructionSet

char InstructionSet[MAX_USER_INSTRUCTION_NUMBER][SLAVE_COMMMAND_STRING_LENGTH]

### 4.12.2.4 iParams

int iParams[MAX_USER_INSTRUCTION_NUMBER]

### 4.12.2.5 MasterInstructionSet

sInstruct MasterInstructionSet[MAX_USER_INSTRUCTION_NUMBER]

### 4.12.2.6 NumOfInstructions

int NumOfInstructions

The documentation for this struct was generated from the following file:

- Master.h

### 58 Data Structure Documentation

# Chapter 5

# File Documentation

## 5.1 Communicative.cpp File Reference

#include <Arduino.h>

#include "Communicative.h" #include "SPI_InstructionSet.h" #include <SPI.h>

Include dependency graph for Communicative.cpp:

Variables

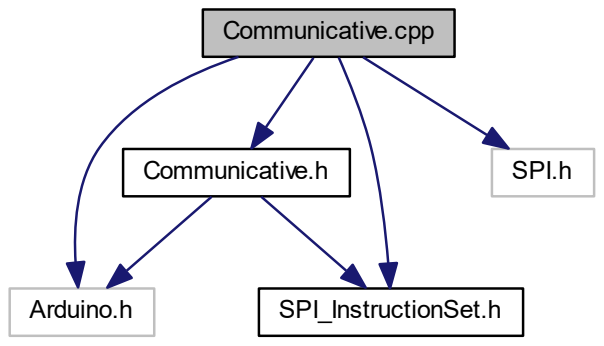
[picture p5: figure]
Communicative.cpp; Arduino.h; Communicative.h; SPI_InstructionSet.h; SPI.h

- const int REQUEST_DELAY_MICROS = 100

### 5.1.1 Variable Documentation

### 60 File Documentation

### 5.1.1.1 REQUEST_DELAY_MICROS

const int REQUEST_DELAY_MICROS = 100

## 5.2 Communicative.h File Reference

#include <Arduino.h>

#include "SPI_InstructionSet.h" Include dependency graph for Communicative.h:

### Communicative.h

Arduino.h | SPI_InstructionSet.h

This graph shows which files directly or indirectly include this file:

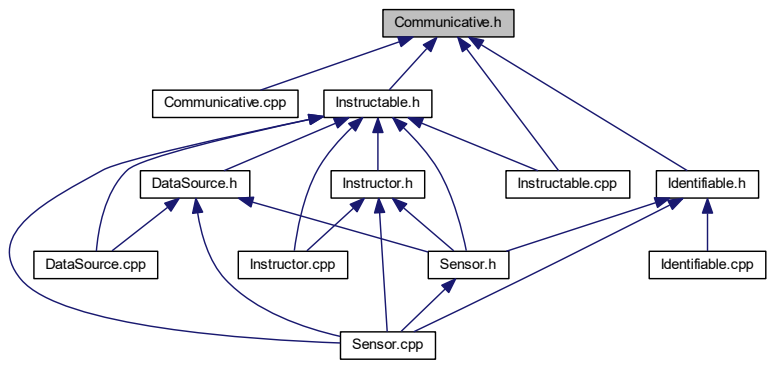
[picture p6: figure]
Communicative.h; Communicative.cpp; Instructable.h; Instructable.cpp; Identifiable.h; DataSource.cpp; DataSource.h; Sensor.cpp; Instructor.cpp; Sensor.h; Instructor.h; Identifiable.cpp

Data Structures

- class Communicative

A class to manage communication with slave module.

5.3 DataSource.cpp File Reference | 61

## 5.3 DataSource.cpp File Reference

#include <Arduino.h>

#include "Instructable.h"

#include "DataSource.h"

#include "SPI_InstructionSet.h" Include dependency graph for DataSource.cpp:

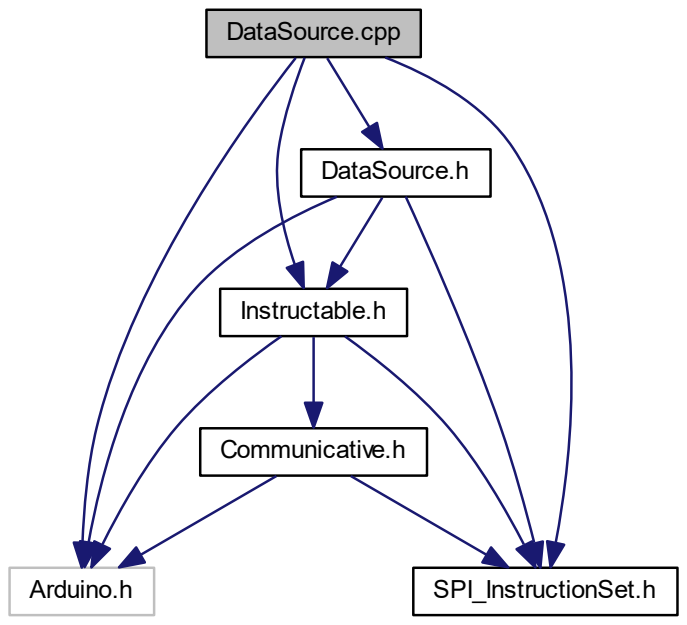
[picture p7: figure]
DataSource.cpp; Arduino.h; Instructable.h; SPI_InstructionSet.h; DataSource.h; Communicative.h

## 5.4 DataSource.h File Reference

#include <Arduino.h>

#include "SPI_InstructionSet.h" #include "Instructable.h"

### 62 File Documentation

Include dependency graph for DataSource.h:

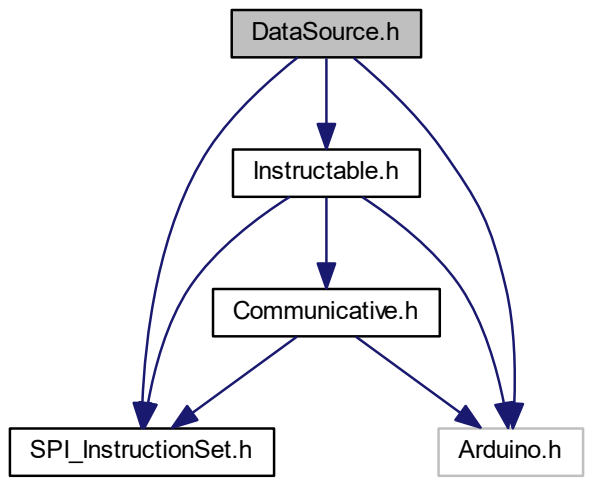
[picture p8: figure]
DataSource.h; SPI_InstructionSet.h; Arduino.h; Instructable.h; Communicative.h

This graph shows which files directly or indirectly include this file:

Data Structures

- class DataSource

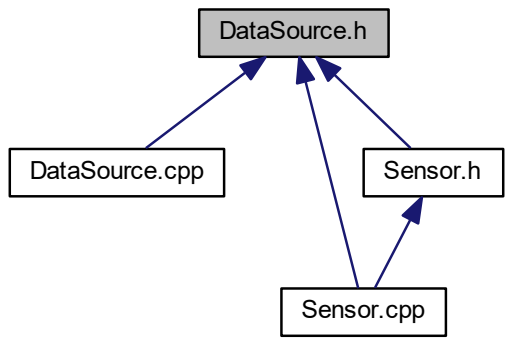
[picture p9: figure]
DataSource.h; DataSource.cpp; Sensor.cpp; Sensor.h

A class which models a Sensor/peripheral as an entity which is a source of data.

5.5 Identifiable.cpp File Reference | 63

## 5.5 Identifiable.cpp File Reference

#include <Arduino.h>

#include "Identifiable.h"

#include "SPI_InstructionSet.h" #include <SPI.h>

Include dependency graph for Identifiable.cpp:

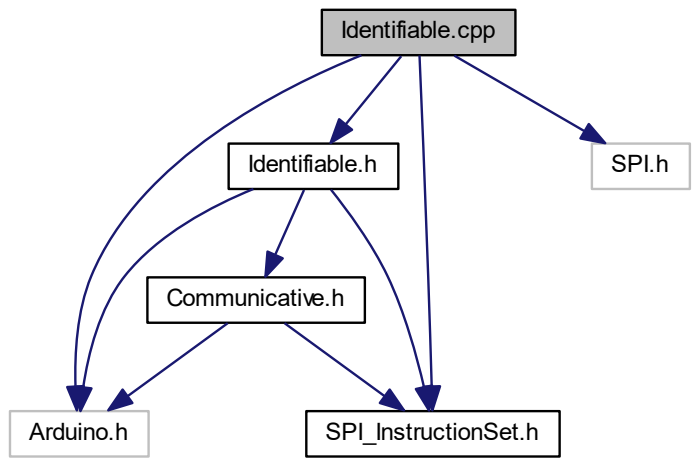
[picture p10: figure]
Identifiable.cpp; Arduino.h; Identifiable.h; SPI_InstructionSet.h; SPI.h; Communicative.h

## 5.6 Identifiable.h File Reference

#include <Arduino.h>

#include "SPI_InstructionSet.h" #include "Communicative.h" Include dependency graph for Identifiable.h:

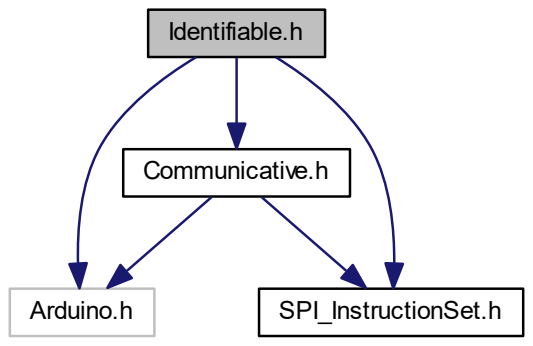
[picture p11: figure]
Identifiable.h; Arduino.h; SPI_InstructionSet.h; Communicative.h

### 64 File Documentation

This graph shows which files directly or indirectly include this file:

Data Structures

- class Identifiable

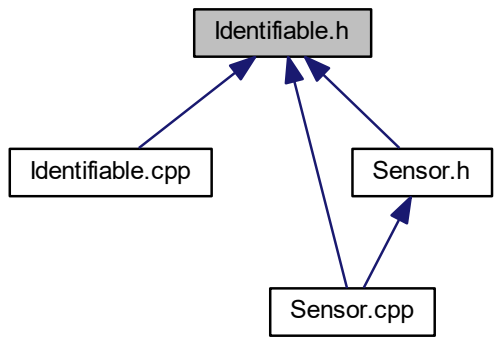
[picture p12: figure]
Identifiable.h; Identifiable.cpp; Sensor.cpp; Sensor.h

A class which models a Sensor/peripheral as an identifiable entity.

## 5.7 Instructable.cpp File Reference

#include <Arduino.h>

#include "Communicative.h" #include "Instructable.h"

#include "SPI_InstructionSet.h"

5.8 Instructable.h File Reference | 65

Include dependency graph for Instructable.cpp:

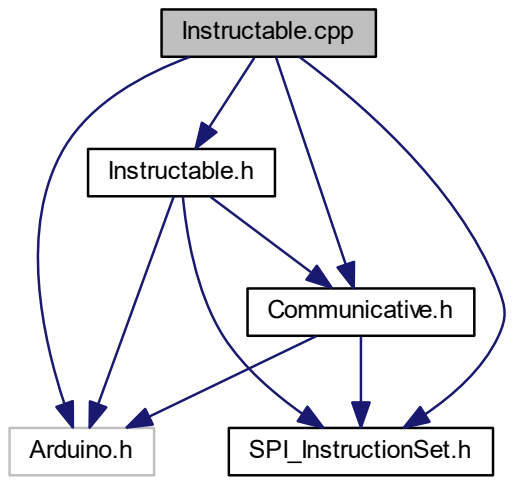
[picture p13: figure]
Instructable.cpp; Arduino.h; Communicative.h; SPI_InstructionSet.h; Instructable.h

## 5.8 Instructable.h File Reference

#include <Arduino.h>

#include "SPI_InstructionSet.h" #include "Communicative.h" Include dependency graph for Instructable.h:

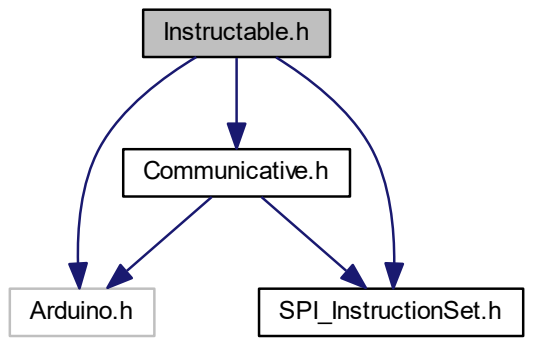
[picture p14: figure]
Instructable.h; Arduino.h; SPI_InstructionSet.h; Communicative.h

### 66 File Documentation

This graph shows which files directly or indirectly include this file:

Data Structures

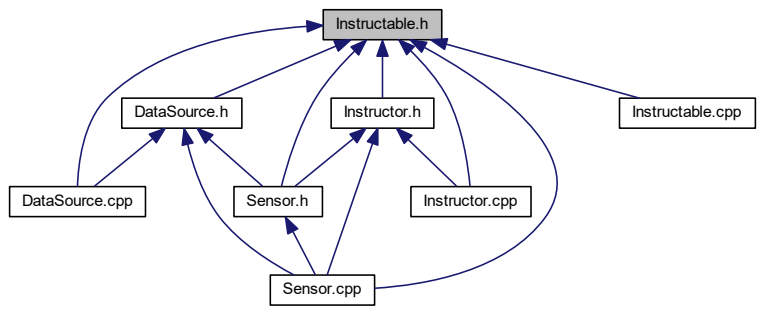
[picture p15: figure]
Instructable.h; DataSource.cpp; DataSource.h; Sensor.cpp; Sensor.h; Instructable.cpp; Instructor.cpp; Instructor.h

- class Instructable

A class which models a Sensor/peripheral as entity which can recieve commands.

## 5.9 Instructor.cpp File Reference

#include <Arduino.h>

#include "Instructable.h"

#include "Instructor.h"

#include "SPI_InstructionSet.h"

5.10 Instructor.h File Reference | 67

Include dependency graph for Instructor.cpp:

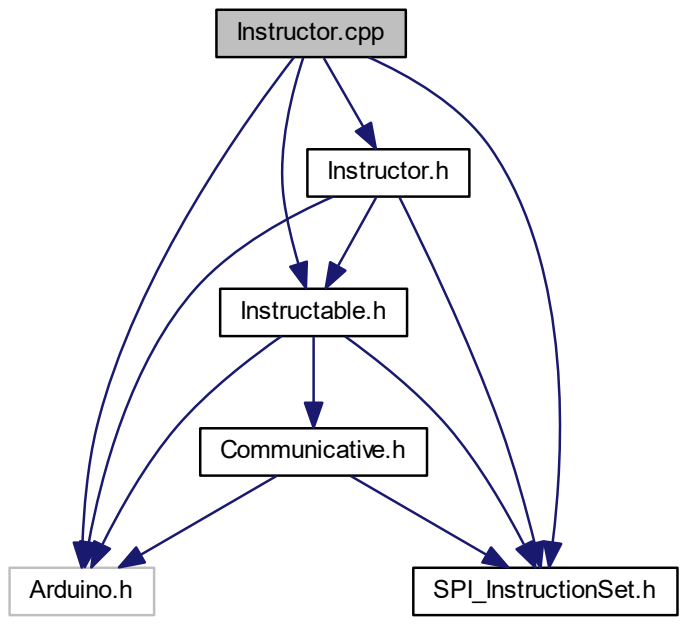
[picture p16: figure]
Instructor.cpp; Arduino.h; Instructable.h; SPI_InstructionSet.h; Instructor.h; Communicative.h

## 5.10 Instructor.h File Reference

#include <Arduino.h>

#include "SPI_InstructionSet.h" #include "Instructable.h"

### 68 File Documentation

Include dependency graph for Instructor.h:

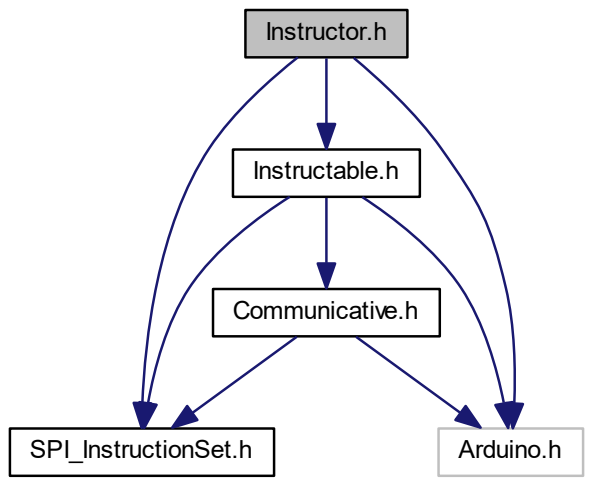
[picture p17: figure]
Instructor.h; SPI_InstructionSet.h; Arduino.h; Instructable.h; Communicative.h

This graph shows which files directly or indirectly include this file:

Data Structures

- class Instructor

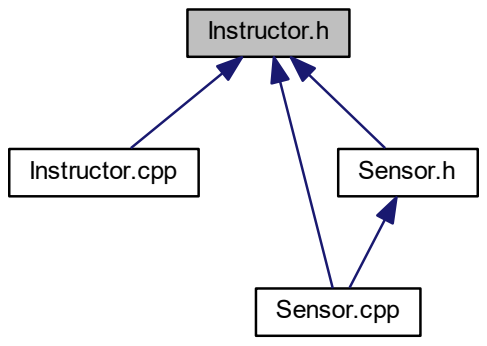
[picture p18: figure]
Instructor.h; Instructor.cpp; Sensor.cpp; Sensor.h

A class which models a Sensor/peripheral as entity which can issue instructions to the master.

5.11 Master.cpp File Reference | 69

## 5.11 Master.cpp File Reference

#include <Arduino.h>

#include "Master.h"

#include "SPI_InstructionSet.h" #include <SPI.h>

#include "SPI_Anything_Slave.h" Include dependency graph for Master.cpp:

Functions

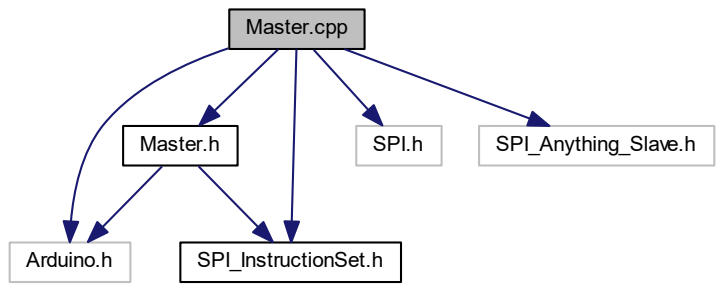
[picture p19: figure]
Master.cpp; Arduino.h; Master.h; SPI_InstructionSet.h; SPI.h; SPI_Anything_Slave.h

- void SPI_IRQ (void)

Innaccesible IRQ, called on SS falling.

Variables

- volatile Master SensorMaster

Auto-instantiated instance of Master class, called during the privately implemented IRQ routine and accessible externally by main code.

### 5.11.1 Function Documentation

### 5.11.1.1 SPI_IRQ()

void SPI_IRQ (

void )

Innaccesible IRQ, called on SS falling.

### 70 File Documentation

Here is the call graph for this function:

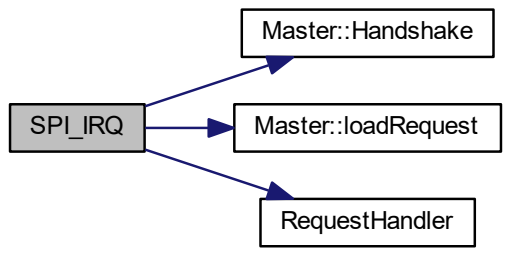
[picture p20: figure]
SPI_IRQ; Master::Handshake; Master::loadRequest; RequestHandler

### 5.11.2 Variable Documentation

### 5.11.2.1 SensorMaster

volatile Master SensorMaster

Auto-instantiated instance of Master class, called during the privately implemented IRQ routine and accessible externally by main code.

## 5.12 Master.h File Reference

#include <Arduino.h>

#include "SPI_InstructionSet.h" Include dependency graph for Master.h:

### Master.h

Arduino.h | SPI_InstructionSet.h | Generated by Doxygen

5.12 Master.h File Reference | 71

This graph shows which files directly or indirectly include this file:

### Master.h

### Master.cpp

Data Structures

- struct UserInstructions
- class Master

A monolithic class to encapsulate and abstract the slave's communication with the master.

Macros

- #define SPI1_NSS_PIN PA4

Functions

- void SPI_IRQ (void)

Innaccesible IRQ, called on SS falling.
- void RequestHandler (mCmd &Request)

Function prototype for user-implemented IRQ method; called after handshake and the reconstruction of the request from the master.

Variables

- const int MAX_USER_INSTRUCTION_NUMBER = 5
- volatile Master SensorMaster

Auto-instantiated instance of Master class, called during the privately implemented IRQ routine and accessible externally by main code.

### 5.12.1 Macro Definition Documentation

### 5.12.1.1 SPI1_NSS_PIN

#define SPI1_NSS_PIN PA4

### 72 File Documentation

### 5.12.2 Function Documentation

### 5.12.2.1 RequestHandler()

void RequestHandler (

mCmd & Request )

Function prototype for user-implemented IRQ method; called after handshake and the reconstruction of the request from the master.

Here is the caller graph for this function:

SPI_IRQ | RequestHandler

### 5.12.2.2 SPI_IRQ()

void SPI_IRQ (

void )

Innaccesible IRQ, called on SS falling.

Here is the call graph for this function:

### SPI_IRQ

### Master::Handshake

### Master::loadRequest

RequestHandler | Generated by Doxygen

5.13 Sensor.cpp File Reference | 73

### 5.12.3 Variable Documentation

### 5.12.3.1 MAX_USER_INSTRUCTION_NUMBER

const int MAX_USER_INSTRUCTION_NUMBER = 5

### 5.12.3.2 SensorMaster

volatile Master SensorMaster

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

## 5.13 Sensor.cpp File Reference

#include <Arduino.h>

#include "DataSource.h"

#include "Instructor.h"

#include "Instructable.h"

#include "Identifiable.h"

#include "Sensor.h"

#include "SPI_InstructionSet.h" Include dependency graph for Sensor.cpp:

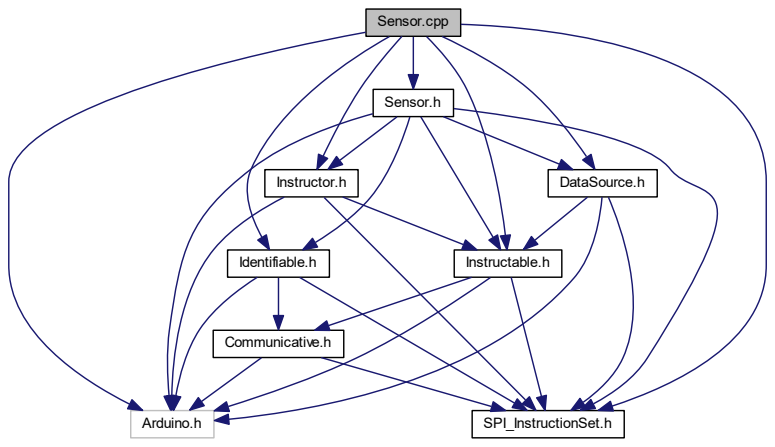
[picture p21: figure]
Sensor.cpp; Arduino.h; DataSource.h; SPI_InstructionSet.h; Instructable.h; Instructor.h; Identifiable.h; Sensor.h; Communicative.h

### 74 File Documentation

## 5.14 Sensor.h File Reference

#include <Arduino.h>

#include "SPI_InstructionSet.h" #include "Instructor.h"

#include "DataSource.h"

#include "Instructable.h"

#include "Identifiable.h"

Include dependency graph for Sensor.h:

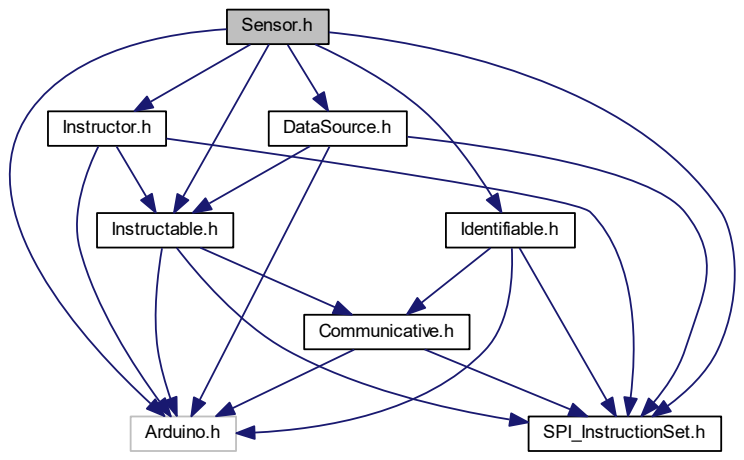
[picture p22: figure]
Sensor.h; Arduino.h; SPI_InstructionSet.h; Instructor.h; Instructable.h; DataSource.h; Identifiable.h; Communicative.h

This graph shows which files directly or indirectly include this file:

### Sensor.h

### Sensor.cpp

Data Structures

- class Sensor

A class which models a Sensor/peripheral.

5.15 SPI_InstructionSet.h File Reference | 75

## 5.15 SPI_InstructionSet.h File Reference

This graph shows which files directly or indirectly include this file:

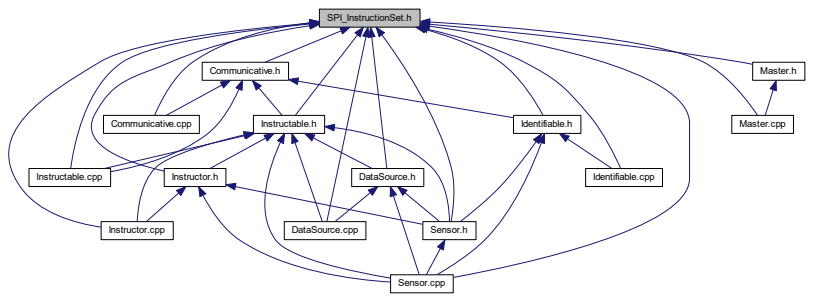
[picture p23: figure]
SPI_InstructionSet.h; Communicative.h; Communicative.cpp; Instructable.h; DataSource.cpp; DataSource.h; Sensor.cpp; Sensor.h; Instructable.cpp; Instructor.cpp; Instructor.h; Identifiable.h; Identifiable.cpp; Master.h; Master.cpp

Data Structures

- struct sCmd

Type used by slave to send reply to master,.
- struct mCmd

Type used by master to send requests to slave.
- struct Identity

Type used to convey the Slave identity.
- struct Data

Type used to encapsulate the data collected by the slave.

Enumerations

- enum sInstruct {
DisplayInstructionAndWait, DisplayInstructionAndWaitForUser, DontDisplayAndWait, DontDisplayAndContinue, ACK, Yes, No, NAK,
ReferToInt, ReferToFloat, ReferToString }

Instruction set used by slave to instruct master.
- enum mInstruct {
PauseMeasurementForiParam, RestartMeasurementProcedure, ResetDevice, HowManyInstructions, NextCommandPlease, IsThereData, SendDataPlease, WhoAreYou,
HowLongShouldIWait, BeginMeasurement, SitRep }

Instruction set used by Master to instruct/request responses from Slave.
- enum MeasurementVectors { First, Second, Third }

Enumeration to provide human-readable references to different rows in the Data array.

Variables

- const int SLAVE_COMMMAND_STRING_LENGTH = 40
- const int IDENTITY_SENSOR_NAME_LENGTH = 25
- const int NUMBER_OF_DATA_ROWS = 3
- const int ROW_HEADING_LENGTH = 10
- const int ROW_UNIT_LENGTH = 5
- const int DATA_ROW_LENGTH = 64

### 76 File Documentation

### 5.15.1 Enumeration Type Documentation

### 5.15.1.1 MeasurementVectors

enum MeasurementVectors

Enumeration to provide human-readable references to different rows in the Data array.

Enumerator

First
Second
Third

### 5.15.1.2 mInstruct

enum mInstruct

Instruction set used by Master to instruct/request responses from Slave.

During a single transaction, the Master will send a request, characterised by an mCmd object, which contains an mInstruct object, integer and float. The mInstruct object will determine how the request is processed by the slave and will define the object type which the master must expect in reply. In general, the master will expect replies in the form of sCmd objects. However, the slave may also send Data and Identity objects in repsonse to specific mInstruct instances; in particular: SendDataPlease and WhoAreYou.

Enumerator

PauseMeasurementForiParam | Require Slave to pause for a duration specified by the integer parameter of mCmd. Expects sCmd{ACK or NAK} in response.
RestartMeasurementProcedure | Require Slave to restart the measurement procedure from the first instruction. Expects sCmd{ACK or NAK} in response.
ResetDevice | Require Slave to reset. Expects sCmd{ACK or NAK} in response.
HowManyInstructions | Request the slave to confirm the number of instructions in a measurement cycle. Expects sCmd{ReferToInt, int NumberOfInstructions} in response.
NextCommandPlease | Request the next instrction in the measurement cycle from the slave. Expects sCmd{sInstruct SomeInstruction, int PotentialIntParam, float PotentialFloatParam, char∗ PotentialStringParam} or sCmd{No} in response.
IsThereData | Requests slave to confirm that Data is ready for collection by master. Expects sCmd{Yes or No}.
SendDataPlease | Require slave to send the data object. Expects Data object in response.
WhoAreYou | Require the slave to send its Identity object; contains char∗ Name and int SensorID. Expects Identity object in response.
HowLongShouldIWait | Ask the slave whether the Master should pause before calling for the next instruction. Unused. Expects sCmd{ReferToInt, int PauseDuration} in reply.
BeginMeasurement | Instruct the slave to initiate its measurement cycle and expect the first instruction to be called for. Expects sCmd{ACK or NAK}.
SitRep | Request good/bad status from slave. Unused. Expects sCmd{} in reply. Generated by Doxygen

5.15 SPI_InstructionSet.h File Reference | 77

### 5.15.1.3 sInstruct

enum sInstruct

Instruction set used by slave to instruct master.

During a single transaction, the master will request a reply, Data or Identity. Replies are characterised by an sCmd object, which contains an sInstruct object, which defines the action which the slave requires of the master.

Enumerator

DisplayInstructionAndWait | Require the master to display the string contained within the sCmd object and pause for a duration defined by the integer parameter of the sCmd object
DisplayInstructionAndWaitForUser | Require the master to display the string contained within the sCmd object and pause until the user has confirmed adherence to the instruction.
DontDisplayAndWait | Require the master to pause for a duration defined by the integer parameter of the sCmd object
DontDisplayAndContinue | Require the master to take no action. Essentially a nop.
ACK | Slave acknowleges the master's command/response.
Yes | Respond affirmative.
No | Respond negative.
NAK | Slave unable to adhere to Master's command or understand it.
ReferToInt | Points master to the integer parameter of sCmd.
ReferToFloat | Points master to the float parameter of sCmd
ReferToString | Points master to the string parameter of sCmd

### 5.15.2 Variable Documentation

### 5.15.2.1 DATA_ROW_LENGTH

const int DATA_ROW_LENGTH = 64

### 5.15.2.2 IDENTITY_SENSOR_NAME_LENGTH

const int IDENTITY_SENSOR_NAME_LENGTH = 25

### 78 File Documentation

### 5.15.2.3 NUMBER_OF_DATA_ROWS

const int NUMBER_OF_DATA_ROWS = 3

### 5.15.2.4 ROW_HEADING_LENGTH

const int ROW_HEADING_LENGTH = 10

### 5.15.2.5 ROW_UNIT_LENGTH

const int ROW_UNIT_LENGTH = 5

### 5.15.2.6 SLAVE_COMMMAND_STRING_LENGTH

const int SLAVE_COMMMAND_STRING_LENGTH = 40

# Index

∼Communicative
Communicative, 8
∼Master
Master, 37

ACK
SPI_InstructionSet.h, 77
areYouConnected
Instructable, 27

BeginMeasurement
SPI_InstructionSet.h, 76
beginMeasurement
Master, 37

ClearMeasurementVector
Master, 37
Communicative, 7
∼Communicative, 8
Communicative, 7
isPeripheralConnected, 8
RequestData, 9
RequestIdentity, 10
RequestReply, 10
Communicative.cpp, 59
REQUEST_DELAY_MICROS, 59
Communicative.h, 60

Data, 11
DataPoints, 12
NumColumns, 12
NumRows, 13
operator=, 12
RowHeadings, 13
rowUnits, 13
DATA_ROW_LENGTH
SPI_InstructionSet.h, 77
DataPoints
Data, 12
DataSource, 13
DataSource, 14
getDataArray, 15
getDataVector, 15
getNumberOfDataColumns, 15 getNumberOfDataRows, 16
getRowHeadings, 16
getRowUnits, 17
getValueOne, 17
getValueThree, 17
getValueTwo, 18

getVectorHeading, 18
getVectorLength, 19
getVectorUnits, 19
isThereData, 19
loadData, 20
DataSource.cpp, 61
DataSource.h, 61
DisplayInstructionAndWait
SPI_InstructionSet.h, 77
DisplayInstructionAndWaitForUser SPI_InstructionSet.h, 77
DontDisplayAndContinue
SPI_InstructionSet.h, 77
DontDisplayAndWait
SPI_InstructionSet.h, 77

First
SPI_InstructionSet.h, 76
fParam
mCmd, 49
sCmd, 51
fParams
UserInstructions, 57

getCurrentCommandFloat
Instructor, 32
getCurrentCommandInstruction Instructor, 32
getCurrentCommandInt
Instructor, 32
getCurrentCommandString
Instructor, 32
getCurrentInstruction
Master, 38
getCurrentInstructionFloatParameter Master, 38
getCurrentInstructionIntParameter Master, 38
getCurrentInstructionNumber Master, 38
getDataArray
DataSource, 15
getDataVector
DataSource, 15
getIDNumber
Identifiable, 22
getNumberOfDataColumns
DataSource, 15
getNumberOfDataRows
DataSource, 16

### 80 INDEX

getRowHeadings
DataSource, 16
getRowUnits
DataSource, 17
getSensorName
Identifiable, 22
getValueOne
DataSource, 17
getValueThree
DataSource, 17
getValueTwo
DataSource, 18
getVectorHeading
DataSource, 18
getVectorLength
DataSource, 19
getVectorUnits
DataSource, 19

Handshake
Master, 38
hasIdentityChanged
Identifiable, 23
HowLongShouldIWait
SPI_InstructionSet.h, 76
howLongShouldIWait
Instructor, 33
HowManyInstructions
SPI_InstructionSet.h, 76
howManyInstructions
Instructor, 33

Identifiable, 21
getIDNumber, 22
getSensorName, 22
hasIdentityChanged, 23
Identifiable, 21
updateIdentity, 23
Identifiable.cpp, 63
Identifiable.h, 63
Identity, 24
operator=, 24, 25
sensorChipSelect, 25
sensorID, 25
SensorName, 25
IDENTITY_SENSOR_NAME_LENGTH SPI_InstructionSet.h, 77
Instructable, 26
areYouConnected, 27
Instructable, 26
issueCommand, 27–29
Instructable.cpp, 64
Instructable.h, 65
Instruction
mCmd, 50
sCmd, 51
InstructionCounter
UserInstructions, 57
InstructionSet

UserInstructions, 57
Instructor, 30
getCurrentCommandFloat, 32 getCurrentCommandInstruction, 32 getCurrentCommandInt, 32
getCurrentCommandString, 32 howLongShouldIWait, 33
howManyInstructions, 33
Instructor, 31
loadNextCommand, 34
Instructor.cpp, 66
Instructor.h, 67
iParam
mCmd, 50
sCmd, 51
iParams
UserInstructions, 57
isPeripheralConnected
Communicative, 8
issueCommand
Instructable, 27–29
IsThereData
SPI_InstructionSet.h, 76
isThereData
DataSource, 19
Master, 39

loadData
DataSource, 20
loadNextCommand
Instructor, 34
loadRequest
Master, 39

Master, 34
∼Master, 37
beginMeasurement, 37
ClearMeasurementVector, 37 getCurrentInstruction, 38
getCurrentInstructionFloatParameter, 38 getCurrentInstructionIntParameter, 38 getCurrentInstructionNumber, 38 Handshake, 38
isThereData, 39
loadRequest, 39
Master, 36, 37
operator=, 40
PopMeasurementVector, 40
PushMeasurementVector, 40
resendCurrentUserInstruction, 41 restartUserInstructionCycle, 41 sendData, 41
sendIdentity, 42
sendNextUserInstruction, 42 sendReply, 42–44
sendTotalNumOfInstructions, 45 setMeasurementVectorHeading, 45 setMeasurementVectorUnits, 45 SETUP, 46

INDEX | 81

shallIStart, 47
SPISetup, 47
Master.cpp, 69
SensorMaster, 70
SPI_IRQ, 69
Master.h, 70
MAX_USER_INSTRUCTION_NUMBER, 73 RequestHandler, 72
SensorMaster, 73
SPI1_NSS_PIN, 71
SPI_IRQ, 72
MasterInstructionSet
UserInstructions, 57
MAX_USER_INSTRUCTION_NUMBER Master.h, 73
mCmd, 48
fParam, 49
Instruction, 50
iParam, 50
mCmd, 49
operator=, 49
MeasurementVectors
SPI_InstructionSet.h, 76
mInstruct
SPI_InstructionSet.h, 76

NAK
SPI_InstructionSet.h, 77
NextCommandPlease
SPI_InstructionSet.h, 76
No
SPI_InstructionSet.h, 77
NUMBER_OF_DATA_ROWS
SPI_InstructionSet.h, 77
NumColumns
Data, 12
NumOfInstructions
UserInstructions, 57
NumRows
Data, 13

operator=
Data, 12
Identity, 24, 25
Master, 40
mCmd, 49
sCmd, 51
UserInstructions, 56, 57

PauseMeasurementForiParam
SPI_InstructionSet.h, 76
PauseMeasurementForMillis
Sensor, 53
PopMeasurementVector
Master, 40
PushMeasurementVector
Master, 40

ReferToFloat

SPI_InstructionSet.h, 77
ReferToInt
SPI_InstructionSet.h, 77
ReferToString
SPI_InstructionSet.h, 77
REQUEST_DELAY_MICROS
Communicative.cpp, 59
RequestData
Communicative, 9
RequestHandler
Master.h, 72
RequestIdentity
Communicative, 10
RequestReply
Communicative, 10
resendCurrentUserInstruction Master, 41
ResetDevice
SPI_InstructionSet.h, 76
RestartMeasurement
Sensor, 55
RestartMeasurementProcedure SPI_InstructionSet.h, 76
restartUserInstructionCycle Master, 41
ROW_HEADING_LENGTH
SPI_InstructionSet.h, 78
ROW_UNIT_LENGTH
SPI_InstructionSet.h, 78
RowHeadings
Data, 13
rowUnits
Data, 13

sCmd, 50
fParam, 51
Instruction, 51
iParam, 51
operator=, 51
sParam, 52
Second
SPI_InstructionSet.h, 76
sendData
Master, 41
SendDataPlease
SPI_InstructionSet.h, 76
sendIdentity
Master, 42
sendNextUserInstruction
Master, 42
sendReply
Master, 42–44
sendTotalNumOfInstructions Master, 45
Sensor, 52
PauseMeasurementForMillis, 53 RestartMeasurement, 55
Sensor, 53
StartMeasurement, 55

### 82 INDEX

Sensor.cpp, 73
Sensor.h, 74
sensorChipSelect
Identity, 25
sensorID
Identity, 25
SensorMaster
Master.cpp, 70
Master.h, 73
SensorName
Identity, 25
setMeasurementVectorHeading Master, 45
setMeasurementVectorUnits
Master, 45
SETUP
Master, 46
shallIStart
Master, 47
sInstruct
SPI_InstructionSet.h, 77
SitRep
SPI_InstructionSet.h, 76
SLAVE_COMMMAND_STRING_LENGTH SPI_InstructionSet.h, 78
sParam
sCmd, 52
SPI1_NSS_PIN
Master.h, 71
SPI_InstructionSet.h, 75
ACK, 77
BeginMeasurement, 76
DATA_ROW_LENGTH, 77
DisplayInstructionAndWait, 77 DisplayInstructionAndWaitForUser, 77 DontDisplayAndContinue, 77 DontDisplayAndWait, 77
First, 76
HowLongShouldIWait, 76
HowManyInstructions, 76
IDENTITY_SENSOR_NAME_LENGTH, 77 IsThereData, 76
MeasurementVectors, 76
mInstruct, 76
NAK, 77
NextCommandPlease, 76
No, 77
NUMBER_OF_DATA_ROWS, 77
PauseMeasurementForiParam, 76 ReferToFloat, 77
ReferToInt, 77
ReferToString, 77
ResetDevice, 76
RestartMeasurementProcedure, 76 ROW_HEADING_LENGTH, 78
ROW_UNIT_LENGTH, 78
Second, 76
SendDataPlease, 76

sInstruct, 77
SitRep, 76
SLAVE_COMMMAND_STRING_LENGTH, 78 Third, 76
WhoAreYou, 76
Yes, 77
SPI_IRQ
Master.cpp, 69
Master.h, 72
SPISetup
Master, 47
StartMeasurement
Sensor, 55

Third
SPI_InstructionSet.h, 76

updateIdentity
Identifiable, 23
UserInstructions, 56
fParams, 57
InstructionCounter, 57
InstructionSet, 57
iParams, 57
MasterInstructionSet, 57
NumOfInstructions, 57
operator=, 56, 57

WhoAreYou
SPI_InstructionSet.h, 76

Yes
SPI_InstructionSet.h, 77

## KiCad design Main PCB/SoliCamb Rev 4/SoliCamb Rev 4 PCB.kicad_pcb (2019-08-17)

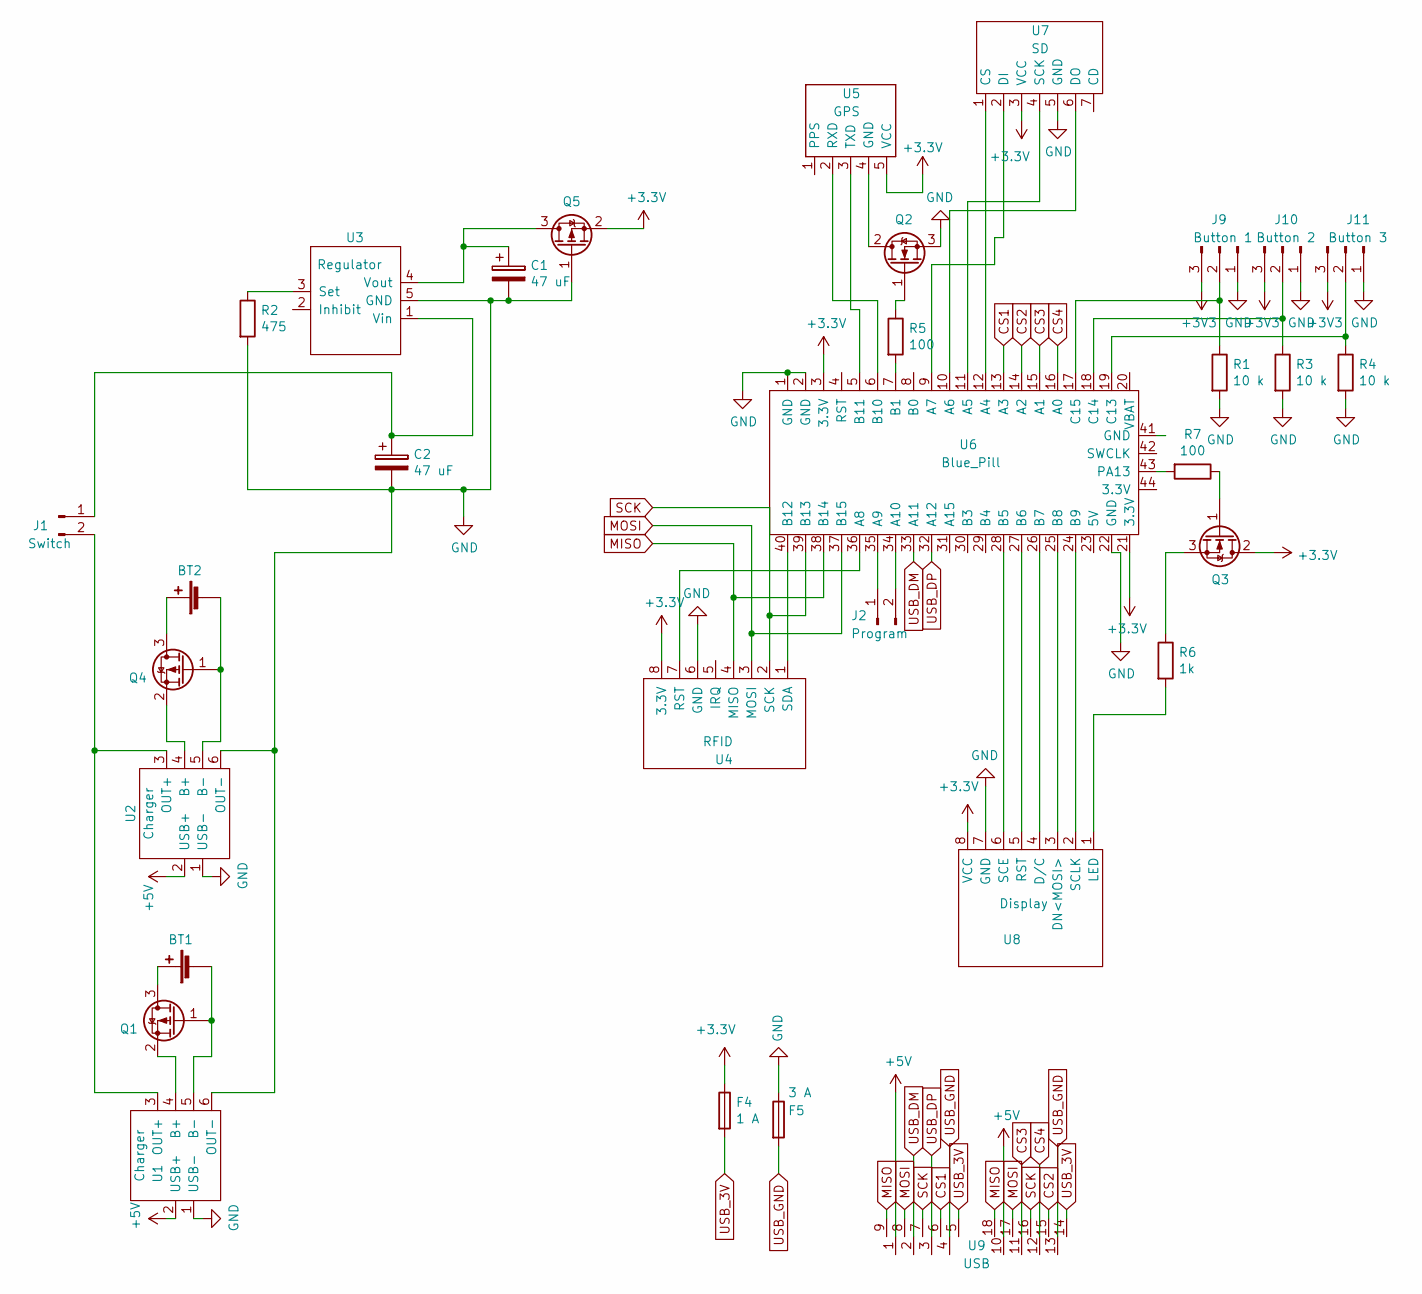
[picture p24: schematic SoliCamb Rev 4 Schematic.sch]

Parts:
BT1, BT2: Battery_Cell; BatteryHolder_Keystone_1042_1x18650
C1, C2: 47 uF; CP_Radial_D4.0mm_P2.00mm
F4: 1 A; R_1812_4532Metric_Pad1.30x3.40mm_HandSolder
F5: 3 A; R_1812_4532Metric_Pad1.30x3.40mm_HandSolder
J1: Switch; PinHeader_1x02_P2.54mm_Vertical_SMD_Pin1Left
J2: Program; PinHeader_1x02_P2.54mm_Vertical_SMD_Pin1Left
J9: Button 1; PinHeader_1x03_P2.54mm_Vertical_SMD_Pin1Left
J10: Button 2; PinHeader_1x03_P2.54mm_Vertical_SMD_Pin1Left
J11: Button 3; PinHeader_1x03_P2.54mm_Vertical_SMD_Pin1Left
Q1, Q4, Q5: Q_PMOS_GSD; SOT-23_Handsoldering
Q2, Q3: Q_NMOS_GDS; SOT-23_Handsoldering
R1, R3: 10 k; R_Axial_DIN0309_L9.0mm_D3.2mm_P12.70mm_Horizontal
R2: 475; R_Axial_DIN0309_L9.0mm_D3.2mm_P12.70mm_Horizontal
R4: 10 k; R_Axial_DIN0411_L9.9mm_D3.6mm_P12.70mm_Horizontal
R5, R7: 100; R_Axial_DIN0309_L9.0mm_D3.2mm_P12.70mm_Horizontal
R6: 1k; R_Axial_DIN0309_L9.0mm_D3.2mm_P12.70mm_Horizontal
U1, U2: Charger; Battery_Charger
U3: Regulator
U4: RFID; PinHeader_1x08_P2.54mm_Vertical
U5: GPS
U6: Blue_Pill; Blue_pill
U7: SD; PinHeader_1x07_P2.54mm_Vertical
U8: Display
U9: USB

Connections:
+5V: U1.2 (USB+), U2.2 (USB+), U9.1, U9.10
CS1: U6.13 (A3), U9.6
CS2: U6.14 (A2), U9.15
CS3: U6.15 (A1), U9.11
CS4: U6.16 (A0), U9.12
GND: C1.2, C2.2, F5.1, J9.1, J10.1, J11.1, Q2.3 (S), Q5.1 (G), R1.2, R2.2, R3.2, R4.2, U1.1 (USB-), U1.6 (OUT-), U2.1 (USB-), U2.6 (OUT-), U3.5 (GND), U4.6 (GND), U6.1 (GND), U6.2 (GND), U6.22 (GND), U7.5 (GND), U8.7 (GND)
MISO: U4.4 (MISO), U6.38 (B14), U9.9, U9.18
MOSI: U4.3 (MOSI), U6.37 (B15), U9.8, U9.17
unnamed: BT1.1 (+), Q1.3 (D)
unnamed: BT1.2 (-), Q1.1 (G), U1.5 (B-)
unnamed: BT2.1 (+), Q4.3 (D)
unnamed: BT2.2 (-), Q4.1 (G), U2.5 (B-)
unnamed: C1.1, Q5.3 (D), U3.4 (Vout)
unnamed: C2.1, J1.1, U3.1 (Vin)
unnamed: J1.2, U1.3 (OUT+), U2.3 (OUT+)
unnamed: J2.1, U6.35 (A9)
unnamed: J2.2, U6.34 (A10)
unnamed: J9.2, R1.1, U6.17 (C15)
unnamed: J10.2, R3.1, U6.18 (C14)
unnamed: J11.2, R4.1, U6.19 (C13)
unnamed: Q1.2 (S), U1.4 (B+)
unnamed: Q2.1 (G), R5.1
unnamed: Q2.2 (D), U5.4 (GND)
unnamed: Q3.1 (G), R7.1
unnamed: Q3.3 (S), R6.1
unnamed: Q4.2 (S), U2.4 (B+)
unnamed: R2.1, U3.3 (Set)
unnamed: R5.2, U6.7 (B1)
unnamed: R6.2, U8.1 (LED)
unnamed: R7.2, U6.43 (PA13)
unnamed: U4.1 (SDA), U6.40 (B12)
unnamed: U4.7 (RST), U6.36 (A8)
unnamed: U5.2 (RXD), U6.6 (B10)
unnamed: U5.3 (TXD), U6.5 (B11)
unnamed: U6.9 (A7), U7.2 (DI)
unnamed: U6.10 (A6), U7.6 (DO)
unnamed: U6.11 (A5), U7.4 (SCK)
unnamed: U6.12 (A4), U7.1 (CS)
unnamed: U6.24 (B9), U8.2 (SCLK)
unnamed: U6.25 (B8), U8.3 (DN<MOSI>)
unnamed: U6.26 (B7), U8.4 (D/C)
unnamed: U6.27 (B6), U8.5 (RST)
unnamed: U6.28 (B5), U8.6 (SCE)
SCK: U4.2 (SCK), U6.39 (B13), U9.7, U9.16
USB_3V: F4.2, U9.5, U9.14
USB_DM: U6.33 (A11), U9.2
USB_DP: U6.32 (A12), U9.3
USB_GND: F5.2, U9.4, U9.13

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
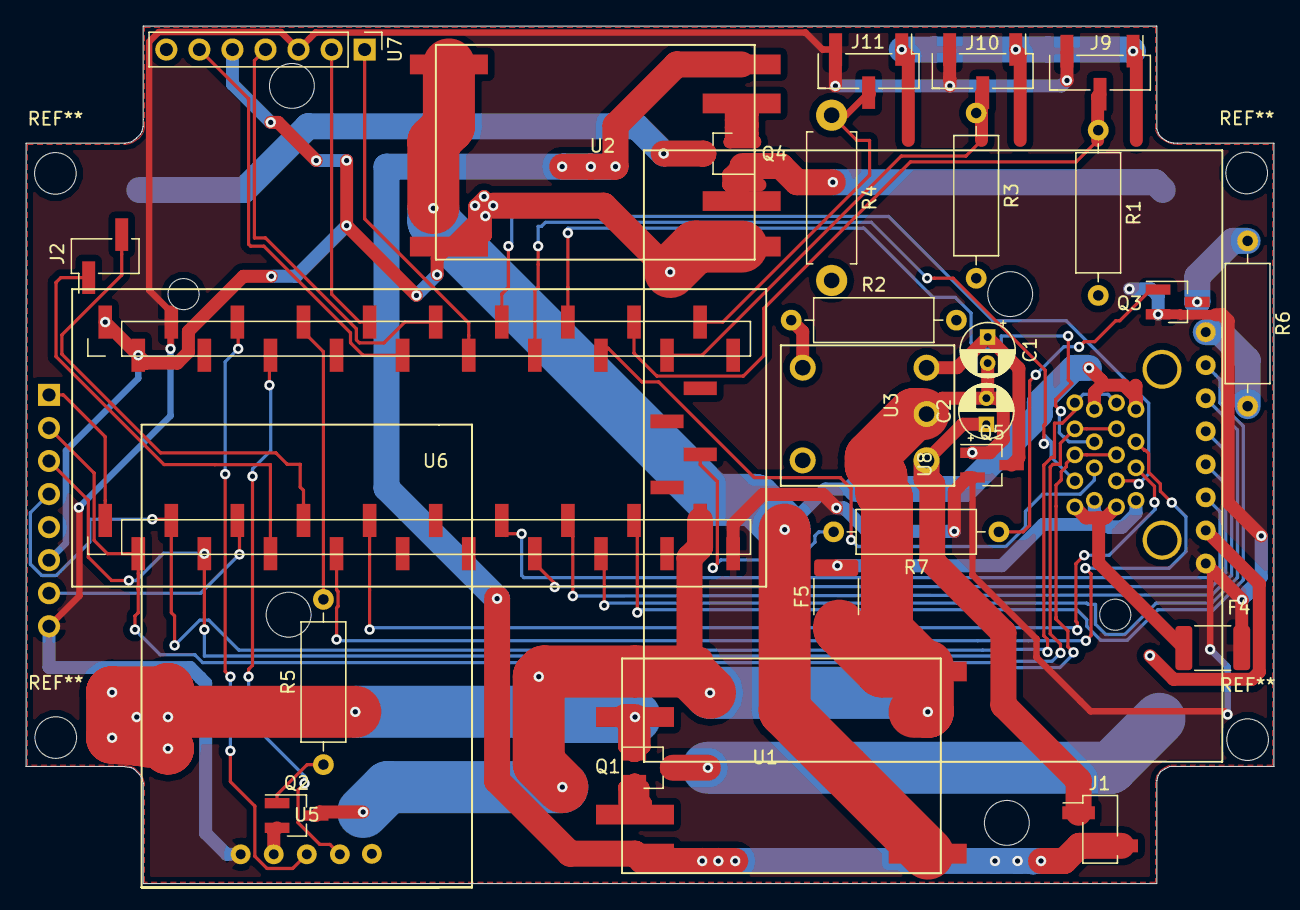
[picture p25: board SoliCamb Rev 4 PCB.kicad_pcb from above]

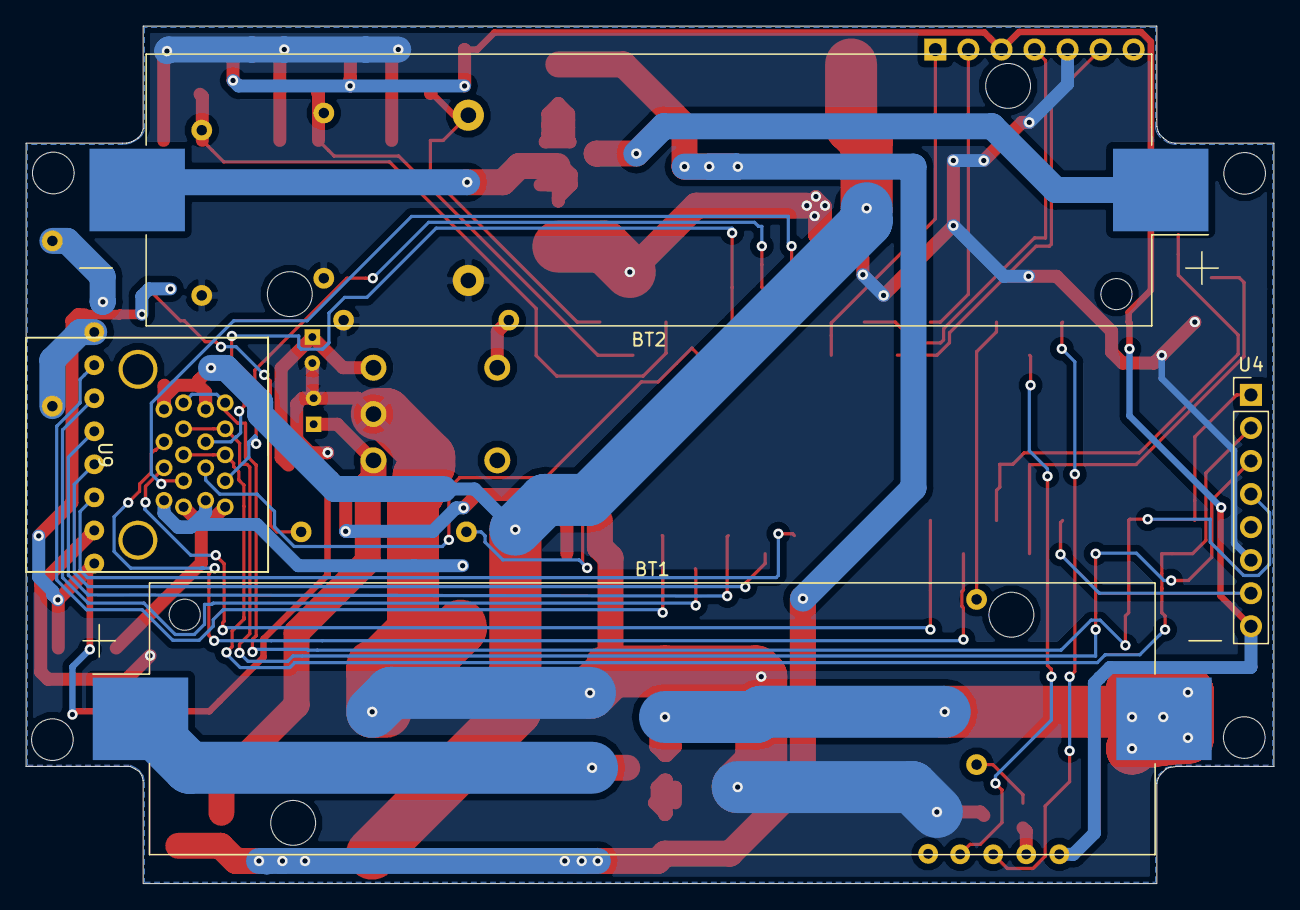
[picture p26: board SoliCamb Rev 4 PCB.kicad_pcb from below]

Board: 2 copper layers, 95.9 x 65.9 mm, 32 parts (4 on the bottom side), 49 nets.

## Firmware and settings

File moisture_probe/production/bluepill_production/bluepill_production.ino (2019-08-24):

/*
 * Production setup for the BluePill controlling the moisture probe (i.e. the slave, the sensor probe)
 *
 * Authors:
 *  Jan (jh2109)
 *
 */

#include <SPI.h>

// User Config
#define BAUDRATE 38400			// μC <=> PC serial baudrate
#define DOWNSAMPLING 10000	// number of ADC readings to average per measurement

#define SLAVE_DEVICE_SERIAL_NUMBER 1 // Serial number for our devices. 0..15

#define NUMBER_OF_SIGNALS 3 // Number of individual capacitive sensing elements (i.e. depths)
#define PROBE_SPACING_CM 15 // Distance interval between probes (cm)

// Debugging Switches
const bool DEBUGGING = true;
const bool DEBUG_WAIT_FOR_MASTER = false;

// Protocol Constants
const int SLAVE_DEVICE_TYPE = 0b00100000;				// Identifies us to the master as a moisture sensor slave device
const uint8_t SPI_CMD_PROBE_INSERTED = 0xF1;		// Sent by master to confirm probe is in ground
// Measurement types precede values sent to master, indicating what kind of data we are sending:
const uint8_t MEASUREMENT_TYPE_MOISTURE_LEVEL = 0x3;
const uint8_t MEASUREMENT_TYPE_MOISTURE_RETENTION_TOPSOIL = 0x4;
const uint8_t MEASUREMENT_TYPE_MOISTURE_RETENTION_MIDSOIL = 0x5;

// Measurement Constants (field-independent calibration)
const float SIGNAL_THRESHOLD_VOLTAGE_DIFFERENCE = -0.40; // threshold to consider a probe wetted. In the future, can extract quantitative (non-binary switchover) data, too
const unsigned long SIGNAL_THRESHOLD_TIMEOUT_MS = 5 * 60 * 1000; // after 5min, stop waiting for bottom-most probe to register a measurement
const float MOISTURE_LEVEL_THRESHOLD_DRY = 2.5;   // voltage above which soil is considered "dry". Only rough estimates are possible, but can still offer a rough guide for the user
const float MOISTURE_LEVEL_THRESHOLD_MOIST = 2.0; // voltage above which soil is considered "moist"
//                                                // voltages below are considered "wet"

const float MOISTURE_RETENTION_SCORE_TIMESCALE_TOPMID = 60.0; // time scaling for moisture retention score. Score is constrained to 0 (measurement failed, e.g. no probes see anything); 1 (very slow, see below); and 2..255 (soil moisture velocity in cm/min)
const float MOISTURE_RETENTION_SCORE_TIMESCALE_MIDBOT = 60.0;

// Pin Config
#define SPI1_SS PA4
// All other SPI1 pins are pre-defined
// NB we use the default pin and therefore don't configure it (only setting it as input with pinMode())

#define ADC_FULL_SCALE_VOLTAGE 4.0f // full scale ADC voltage for scaling
// NB While this will correspond to VCC, don't assume the VCC=3.3V pin will have exactly that voltage
// One measurement gave 4V when powered via USB from a PC, hence this choice; other power sources will differ
// Ultimately, we should control/know what VCC we are referencing to. On the other hand, this scaling is only
// to make it more physically meaningful; we can also just think in terms of percentage of full scale
// All derived algorithms are scale invariant, hence this is not an issue
#define ADC_FULL_SCALE_VALUE 4095 // 12 bit resolution for blue pill

// Global scope variables
float calibration[NUMBER_OF_SIGNALS] = {};
bool measurement_in_progress = false;
unsigned long signal_detected_timer[NUMBER_OF_SIGNALS] = {};
bool signal_detected_bool[NUMBER_OF_SIGNALS] = { false, false, false};


void setup() {
	// Initialise serial
  Serial.begin(BAUDRATE);
	while (!Serial){
		// nop until serial becomes available
	}

	Serial.flush();
	Serial.println();
	delay(10); // give PC serial monitor time to catch up; otherwise we catch garbled mess at start
	Serial.println("START");

	// Set up pins (commented-out ones are predefined, so are skipped, but left in the code as a reminder)
	/*pinMode(SPI1_CLK, INPUT);*/
	/*pinMode(SPI1_MISO, OUTPUT);*/
	/*pinMode(SPI1_MOSI, INPUT);*/
	pinMode(SPI1_SS, INPUT);
  
  SPI.setModule(1);
  SPI.beginTransactionSlave(SPISettings(0, MSBFIRST, SPI_MODE0, DATA_SIZE_8BIT));
  // NB The clock value is not used, as we are a slave device; hence arbitrarily choose 0

  // Data that master will receive when transferring a data frame over SPI
	SPI.dev()->regs->DR = 10; // TODO think about what is most meaningful here

	Serial.println("INFO: Waiting until USB connection is debounced");
	delay(1000); // Debouncing of USB connection

	initiate_communication_with_master();
}

float read_average_ADC(int pin, int n){
	// Read ADC on $pin, taking the average of $n samples, and return reading in volt
	long sum = 0;
	for (int i = 1; i <= n; i++){
		sum += analogRead(pin);
	}

	float voltage = (float)sum/n; // average
	voltage *= ADC_FULL_SCALE_VOLTAGE/ADC_FULL_SCALE_VALUE; // convert to volt

	return voltage;
}

void write_measurement_to_serial(char const variable_name[], float value){
	// Send a measurement to the PC via Serial in the format that the Python script expects
	// One could make an argument to take the time of sampling rather than comunication, but ignore this difference for now
	Serial.print(variable_name);
	Serial.print(";");
	Serial.print(millis());
	Serial.print(";");
	Serial.println(value);
}

void initiate_communication_with_master(){
	// Tell master who we are
	// Specified format: upper nibble ID, lower nibble serial number
	Serial.print("INFO: Identifying ourselves to Master with ID+S/N 0x");
	Serial.println(SLAVE_DEVICE_TYPE | SLAVE_DEVICE_SERIAL_NUMBER, HEX);
	
	if (DEBUG_WAIT_FOR_MASTER){
		SPI.transfer(SLAVE_DEVICE_TYPE | SLAVE_DEVICE_SERIAL_NUMBER);
	}

	return;
}

void send_measurement_to_master(uint8_t measurement_type, uint8_t measurement_value){
	// Report a measurement $value of type $measurement_type to the master
	if (DEBUG_WAIT_FOR_MASTER){
		Serial.print("INFO: Sending to master: measurement_type: 0x");
		Serial.println(measurement_type, HEX);
		SPI.transfer(measurement_type);

		Serial.print("INFO: Sending to master: measurement_value: ");
		Serial.println(measurement_value);
		SPI.transfer(measurement_value);
	}
	else {
		Serial.print("INFO: Skipping SPI transfer (DEBUG_WAIT_FOR_MASTER=false): type=");
		Serial.print(measurement_type);
		Serial.print(" val=");
		Serial.println(measurement_value);
	}
}

float return_calibrated_value(float raw_voltage, int signal_id){
	// Return calibrated measurement of signal $signal_id, with raw voltage reading $raw_voltage
	// Calibration values are held in the global variable calibration[]
	return raw_voltage - calibration[signal_id];
}
	
void evaluate_moisture_retention_score(float signals[], unsigned long signal_detected_timer[], uint8_t moisture_retention_scores[]){
	// Estimate scores (1..100) for moisture retention quality
	// Higher scores mean better quality, i.e. allows for water to percolate into the ground quicker

	// Topsoil to Midsoil
	long time_difference = (signal_detected_timer[1] - signal_detected_timer[0]) / 1000; // ms -> s

	if (time_difference < 0){
		Serial.println("WARN: Middle probe reached before top one. Invalid measurement");
		moisture_retention_scores[0] = 0; // invalidate measurement
	}
	else {
		float moisture_velocity = PROBE_SPACING_CM / (time_difference / MOISTURE_RETENTION_SCORE_TIMESCALE_TOPMID);
		moisture_retention_scores[0] = constrain((uint8_t)moisture_velocity, 1, 255);
	}

	// Midsoil to Bottomsoil
	time_difference = (signal_detected_timer[2] - signal_detected_timer[1]) / 1000; // ms -> s

	if (time_difference < 0){
		Serial.println("WARN: Bottom probe reached before middle one. Invalid measurement");
		moisture_retention_scores[1] = 0; // invalidate measurement
	}
	else {
		float moisture_velocity = PROBE_SPACING_CM / (time_difference / MOISTURE_RETENTION_SCORE_TIMESCALE_MIDBOT);
		moisture_retention_scores[1] = constrain((uint8_t)moisture_velocity, 1, 255);
	}
}

bool is_measurement_complete(float signals[], unsigned long signal_detected_timer[]){
	// Return true if all needed measurements have been done (i.e., water has reached all the probes,
	// or second one has never been wetted (very bad soil))

	for (int i = 0; i < NUMBER_OF_SIGNALS; i++){
		if (signals[i] < SIGNAL_THRESHOLD_VOLTAGE_DIFFERENCE && signal_detected_timer[i] != 0){
			// TODO we might have to consider signals going up because of probe movement -- only look at downwards signal, and increase threshold
			// Signal threshold has been reached (for the *first* time)
			Serial.print("INFO: Signal threshold reached on probe A");
			Serial.println(i);
			signal_detected_timer[i] = millis();
			signal_detected_bool[i] = true;
		}
	}

	if (signal_detected_timer[0] != 0){
		unsigned long time_elapsed = millis() - signal_detected_timer[0];
		if (time_elapsed > SIGNAL_THRESHOLD_TIMEOUT_MS){
			Serial.print("INFO: Timeout to have all probes register a moisture reading (water has not reached down all the way) after ");
			Serial.print(time_elapsed);
			Serial.println("ms");
			Serial.println("INFO: Finishing measurement");
			return true;
		}
	}

	/*return DEBUG_WAIT_FOR_MASTER; // True in normal operation; in debugging, this means we never reach measurement done to keep logging indefinitely*/
	bool all_probes_registered_reading = (signal_detected_bool[0] == true) && (signal_detected_bool[1] == true) && (signal_detected_bool[2] == true);
	return all_probes_registered_reading;
}

uint8_t getMoistureLevel(float raw_voltages[], int signal_id){
	if (raw_voltages[signal_id] > MOISTURE_LEVEL_THRESHOLD_DRY){ return 1; } // dry
	if (raw_voltages[signal_id] > MOISTURE_LEVEL_THRESHOLD_MOIST){ return 2; } // moist
	else { return 3; } // wet
}

void loop() {
	float raw_voltages[NUMBER_OF_SIGNALS];
	float signals[NUMBER_OF_SIGNALS];
	char signal_id_string[2] = ""; // will hold the (ASCII) number added to the signal name
	int adc_pin = PA0; // We assume three sequential pins, starting with this one. If not, need to implement pin mapping

	// For all signals (measurements):
	for (int i = 0; i < NUMBER_OF_SIGNALS; i++){
		// Measure and report raw data via serial
		raw_voltages[i] = read_average_ADC(adc_pin + i, DOWNSAMPLING);
		char signal_name[20] = "y"; // maximum length hardcoded, adjust if using longer signal names
		signal_id_string[0] = '0' + i; // convert int->ASCII by simple addition. itoa() not in stdlib
		strcat(signal_name, signal_id_string); // append signal index to form "y0" etc
		write_measurement_to_serial(signal_name, raw_voltages[i]);

		// Calibrate values, send to serial
		signals[i] = return_calibrated_value(raw_voltages[i], i);
		strcpy(signal_name, "calibrated");
		strcat(signal_name, signal_id_string);
		write_measurement_to_serial(signal_name, signals[i]);
	}

	if (DEBUG_WAIT_FOR_MASTER == false){
		// Immediately go to measurement mode when debugging flag is set
		measurement_in_progress = true;
	}

	if (measurement_in_progress == true){
		if (calibration[0] == 0){
			// Not yet calibrated: user has now confirmed that probe has been inserted into ground
			Serial.println("INFO: Setting calibration from previous reading");
			memcpy(&calibration, &raw_voltages, sizeof(calibration));

			// We determine the absolute moisture level (wetness) before irrigation based on their constant voltage drop
			Serial.println("INFO: Calculating absolute moisture level (wetness)");
			for (int i = 0; i < NUMBER_OF_SIGNALS; i++){
				// Measure
				uint8_t moisture_level = getMoistureLevel(raw_voltages, i);

				// Send it out to master
				send_measurement_to_master(MEASUREMENT_TYPE_MOISTURE_LEVEL, moisture_level);
			}

			// Start timer for irrigation measurement (moisture retention)
			Serial.print("INFO: Starting irrigation measurement at ");
			/*memset(&signal_detected_timer, millis(), sizeof(signal_detected_timer));*/
			unsigned long time_now = millis();
			signal_detected_timer[0] = time_now;
			signal_detected_timer[1] = time_now;
			signal_detected_timer[2] = time_now;
			Serial.print(signal_detected_timer[0]);
			Serial.println("ms");

			// Return to main loop, starting continuous measurements
			return;
		}
		
		if (is_measurement_complete(signals, signal_detected_timer)){
			// All depths of the probe have received a signal from irrigated water
			Serial.println("INFO: Measurement completed");

			// Moisture retention algorithm
			uint8_t moisture_retention_scores[NUMBER_OF_SIGNALS - 2] = {};
			evaluate_moisture_retention_score(signals, signal_detected_timer, moisture_retention_scores);

			if (DEBUG_WAIT_FOR_MASTER == false){
				Serial.println("INFO: DEBUG: Measurement completed, skipping transfer to master");
				return;
			}
		
			// Communicate result to master via SPI
			send_measurement_to_master(MEASUREMENT_TYPE_MOISTURE_RETENTION_TOPSOIL, moisture_retention_scores[0]);
			send_measurement_to_master(MEASUREMENT_TYPE_MOISTURE_RETENTION_MIDSOIL, moisture_retention_scores[1]);

			// We are done with what we are meant to do. We could now nop forever, instead be a bit more verbose:
			while (true){
				Serial.println("INFO: Finished. You may disconnect the probe from the main device. Execution stopped");
				delay(1000);
			}
		}
	}
	else {
		// No measurement in progress yet (i.e. probe has not been inserted into ground)
		Serial.println("INFO: Waiting for master to confirm probe has been inserted");

		// Read from master
		uint8_t spi_rec_msg = SPI.transfer(0);

		// Compare to expected command constant
		if (spi_rec_msg == SPI_CMD_PROBE_INSERTED){
			measurement_in_progress = true;
		}
		else {
			Serial.print("WARN: received unexpected code from master: 0x");
			Serial.println(spi_rec_msg, HEX);
		}
	}
}

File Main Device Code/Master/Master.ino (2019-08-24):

/*Copyright (c) 2019 Sagnik Middya and James Meech

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
Authored by Sagnik Middya and James Meech
*/


#include <TinyGPS++.h> 
#include <SPI.h>
#include <MFRC522.h>
#include <Adafruit_GFX.h>
#include <Adafruit_PCD8544.h>
#include "SdFat.h"
#include <Sensor.h>
#include "SPI_anything.h"

#define RST_PIN         PA8          // Reset pin for RFID board
#define SS_PIN          PB12         // Chip select for RFID board
const uint8_t chipSelect = PA4;         // Chip select for SD
#define sensor_ss_pin   PA1

//---------------------------All function instances required-------------------------------
TinyGPSPlus gps;
SdFat sd;
SdFile file;
SPIClass SPI_2(2); //SPI2 for RFID
SPIClass SPI_3(3);

Adafruit_PCD8544 display = Adafruit_PCD8544(PB9, PB8, PB7, PB5, PB6);  //in latest version: PA12 goes to PB7,PA11 goes to pb6

Sensor sensor(sensor_ss_pin);

//--------------------------All variable definitions below -------------------------------------

char fileName[9] = "data.csv";

//MFRC522 mfrc522(SS_PIN, RST_PIN);  // Create MFRC522 instance
unsigned long value;

//SoliCamb logo bitmap
const unsigned char solicamb_logo [] PROGMEM = {
0xff, 0xff, 0xff, 0xff, 0xff, 0x80, 0xff, 0xff, 0xff, 0xff, 0xff, 0x80, 0xff, 0xfe, 0x00, 0x7f, 
  0xff, 0x80, 0xff, 0xf1, 0xff, 0x0f, 0xff, 0x80, 0xff, 0xe7, 0xff, 0xf3, 0xff, 0x80, 0xff, 0x9f, 
  0xff, 0xfd, 0xff, 0x80, 0xff, 0x7f, 0xcf, 0xfe, 0xff, 0x80, 0xfe, 0xff, 0xc7, 0xff, 0x7f, 0x80, 
  0xfd, 0xff, 0xc7, 0xff, 0xbf, 0x80, 0xfb, 0xff, 0xc3, 0xff, 0xdf, 0x80, 0xf7, 0xff, 0xc3, 0xff, 
  0xdf, 0x80, 0xf7, 0xdf, 0xc3, 0xff, 0xef, 0x80, 0xef, 0xe3, 0xc3, 0x83, 0xf7, 0x80, 0xef, 0xe0, 
  0xc2, 0x03, 0xf7, 0x80, 0xef, 0xe0, 0x64, 0x07, 0xf7, 0x80, 0xdf, 0xf0, 0x24, 0x0f, 0xfb, 0x80, 
  0xdf, 0xf8, 0x38, 0x1f, 0xfb, 0x80, 0xdf, 0xfc, 0x18, 0x3f, 0xfb, 0x80, 0xdf, 0xff, 0xe7, 0xff, 
  0xfb, 0x80, 0xdf, 0xff, 0xe7, 0xff, 0xfb, 0x80, 0xdf, 0xff, 0xe7, 0xff, 0xfb, 0x80, 0xdf, 0xff, 
  0xe7, 0xff, 0xfb, 0x80, 0xc0, 0x00, 0x20, 0x00, 0x03, 0x80, 0xc0, 0x07, 0xe7, 0xc0, 0x03, 0x80, 
  0xc0, 0x06, 0x01, 0x40, 0x03, 0x80, 0xc0, 0x06, 0xec, 0x40, 0x03, 0x80, 0xe0, 0x04, 0xef, 0x40, 
  0x07, 0x80, 0xe0, 0x7d, 0xef, 0x40, 0x07, 0x80, 0xf0, 0x41, 0xef, 0x40, 0x0f, 0x80, 0xf0, 0x4d, 
  0x8f, 0x40, 0x0f, 0x80, 0xf8, 0x79, 0xbb, 0x78, 0x1f, 0x80, 0xfc, 0x03, 0x33, 0x0c, 0x3f, 0x80, 
  0xfe, 0x03, 0x5f, 0x8c, 0x7f, 0x80, 0xff, 0x01, 0xdf, 0xf8, 0xff, 0x80, 0xff, 0x80, 0x19, 0x91, 
  0xff, 0x80, 0xff, 0xc0, 0x1d, 0x83, 0xff, 0x80, 0xff, 0xf0, 0x07, 0x0f, 0xff, 0x80, 0xff, 0xfc, 
  0x00, 0x3f, 0xff, 0x80, 0xff, 0xff, 0xff, 0xff, 0xff, 0x80, 0xff, 0xff, 0xff, 0xff, 0xff, 0x80, 
  0xe3, 0x37, 0x63, 0x3b, 0x63, 0x80, 0xde, 0x97, 0x6e, 0x13, 0x2d, 0x80, 0xcc, 0xd7, 0x4e, 0xd0, 
  0x21, 0x80, 0xf4, 0xd7, 0x4e, 0x14, 0xad, 0x80, 0xf2, 0x97, 0x6e, 0xd4, 0xad, 0x80, 0xc6, 0x31, 
  0x62, 0xd7, 0xa3, 0x80, 0xff, 0xff, 0xff, 0xff, 0xff, 0x80, 0xff, 0xff, 0xff, 0xff, 0xff, 0x80,  
};

int contrast=50;

int menuitem = 1;
int page = 1;

volatile boolean cancel = false;
volatile boolean down = false;
volatile boolean middle = false;

int downButtonState = 1;
int cancelButtonState = 1;  
int selectButtonState = 1;          
int lastDownButtonState = 1;
int lastSelectButtonState = 1;
int lastCancelButtonState = 1;

int rfid_flag=0;
int color_flag=0;
int moisture_flag=0;

float nitrate = 0;
float pH = 0;
uint8_t wetness_top = 0;
uint8_t wetness_mid = 0;
uint8_t wetness_bot = 0;
uint8_t moisture_score_top = 0;
uint8_t moisture_score_mid = 0;
char sensorID;
int serialnumber = 0;
char colorID = 0;
int color_serial = 0;
char moistureID = 0;
int moisture_serial = 0;
#define deviceID 4

uint8_t SPIreceived = 0;
//----------------------------------------------------------------------------

void setup()
{
  pinMode(chipSelect, OUTPUT);
  pinMode(SS_PIN, OUTPUT);
  pinMode(PC14, INPUT_PULLDOWN);
  pinMode(PC13, INPUT_PULLDOWN);
  pinMode(PC15, INPUT_PULLDOWN);
  pinMode(PB9, OUTPUT);
  pinMode(sensor_ss_pin, OUTPUT);
  digitalWrite(sensor_ss_pin, HIGH);
  digitalWrite(PB1, HIGH);
  digitalWrite(PA13, LOW);   // for switching off screen LED

  // connect at 115200 so we can read the GPS fast enough and echo without dropping chars
  // also spit it out
  Serial.begin(115200);
  Serial2.begin(9600);
   Serial.println("right after serial begin");
  delay(1000);
  SPI.begin();
  SPI_2.begin();
  Serial.println("before logo display"); 
  

  //---------Start display and show logo-----------------------
  display.begin();      
  Serial.println("just after display begin");
  display.setContrast(57);
  display.clearDisplay();
  display.display(); 
  
  //display the logo
  display.setRotation(2);
  display.drawBitmap(20, 0,  solicamb_logo, 42, 48, BLACK);
  display.display();
  delay(2500);
  display.clearDisplay();

  Serial.println("just after logo display");

  //---------Sd card initiation------------------------------------
  display.setTextSize(1);
  display.setTextColor(BLACK, WHITE);
  display.setCursor(0, 0);
  display.print("SD card initiation");
    
  if (!sd.begin(chipSelect, SPI_HALF_SPEED)) {
    sd.initErrorHalt();
  }

  if (!sd.exists(fileName)){
  file.open(fileName, O_WRITE | O_CREAT);
  writeHeader();
  delay(1000);
   if (!file.sync() || file.getWriteError()) {
    Serial.println("Synching write error");
  }
  file.close();
  file.flush();
  //-----------------------------------------------------------------------

  
}
drawMenu();
}
//uint32_t timer = millis();
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

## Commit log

2019-07-16 Initial commit of the README for the moisture probe subfolder
2019-07-25 Renamed files according to Arduino naming convention (file and folder name identical)
2019-07-25 Rename to Arduino naming conventions File and folder name must be identical
2019-07-25 .gitignore: Ignore moisture-probe/plot/data dir These files contain measurement data not relevant to this code repository
2019-07-25 Initial commit for data analysis and plotting file This takes all .csv files (as command line arguments) from what the live_plot.py script produced, and turns them into plots for visual analysis. Cal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
2019-07-29 Duplicate Arduino code: begin porting to bluepill
2019-07-29 Allow different ADC full scale voltage; resolution
2019-07-30 Initial Commit
    Added standard Arduino library templates
2019-07-31 Initial commit for the production code This is what will run on the slave device (bluepill, not Arduino). Still early stage but basic communication is working
2019-08-01 Disabled waiting for START (bluepill issue) See comment in file for reasoning
    [live_plot.py]
2019-08-01 Minimum Working Example From http://www.gammon.com.au/spi
2019-08-03 Stubbed out functions for program logic flow
2019-08-05 Moved base class into composition to avoided the dreaded diamond
    Potential problem: composed class Communicative needs to know or recieve ChipSelect. To know to be redundant, to receive is to have polymorphic issues or reintroduce diamondality.
    [Communicative.cpp]
2019-08-07 Branching here to work on STM32 platforms
2019-08-07 Basic STM32, interrupt driven SPI
    Can't get the native spi_rx interrupt to run. So using attachInterrupt() on the SS pin
2019-08-08 Encapsulated interrupt; messy
2019-08-08 Encapsulated Interrupt; cleaned up
2019-08-09 Refactoring. Comments; Skipped another SPI transfer in debugging mode
    [bluepill_production.ino]
2019-08-12 Implemented moist. ret. algorithm framework Also included delay before initial SPI communication. Sometimes, USB connection caused bouncing issues causing master and slave to loose sync
    [bluepill_production.ino]
2019-08-13 Updates and bugfixes to MR algorithm
    [bluepill_production.ino]
2019-08-16 Soil moisture velocity now in cm/min Idea is to restrict citizen scientist less in the range of readings; have them take several readings to see what range their soil falls into
2019-08-17 added PCB, BOM to do
    [SoliCamb Rev 4 PCB-B.Adhes.gbr, SoliCamb Rev 4 PCB-B.CrtYd.gbr, SoliCamb Rev 4 PCB-B.Cu.gbr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]
2019-08-24 Added sensor library
